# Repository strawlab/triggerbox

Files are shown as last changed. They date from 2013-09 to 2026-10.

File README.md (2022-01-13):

# triggerbox - camera triggering for synchronized multi-camera setups

## Principle of operation

Cameras trigger inputs are connected to pin D9 on an Arduino. (Optionally, a
buffer amplifier can be used. See below for why this may be a good idea.) This
is used to generate a digital pulse which triggers image acquisition on cameras.
Furthermore, a host PC communicates with the Arduino to build a live model of
the clocks on both systems and allows very precise (sub-millisecond)
determination of the timing of trigger pulses from the Arduino. This allows
precise timing information to be taken from the resulting acquired image frames.

## Required hardware:

The minimal required hardware is this:

 - Arduino Nano A000005 (later models WILL NOT WORK).

If using the minimal hardware, you will need to connect pin D9 to the trigger
inputs of your camera directly.

## Optional buffer amplified and circuit board:

For additional robustness for multi-camera setups, particularly those that have
an opto-coupled trigger input which accordingly draws substantially more
current, you will want a buffer amplifier to trigger more cameras. In the
`hardware_v1` and `hardware_v2` directories are the PCB layouts, schematics, and enclosure of the triggerbox.
- Hardware_v1: BNC outputs for triggering only
- Hardware_v2: 4-pin terminal block ouputs for triggering and powering the cameras via external powersource.

## Firmware Build and Install

This firmware can be compiled and installed with the Arduino IDE or at
the command line.

### Option 1: Compiling and Uploading using the Arduino IDE

The file `triggerbox.ino` can be opened directly in the [Arduino
IDE](http://arduino.cc/en/main/software). Set your board to Arduino Nano
("Tools"->"Board"->"Arduino Nano"). Set your port ("Tools"->"Port") correctly,
which depends on your specific computer setup. Then click the "Upload" button.

### Option 2: Command-line Compiling and Uploading using Arduino CLI

To build this firmware for an Arduino Nano on Ubuntu linux, do the following
steps.

Install the required software:

Intall [Arduino CLI](https://arduino.github.io/arduino-cli/latest/), then:

    arduino-cli core update-index
    arduino-cli core install arduino:avr

Compile the firmware

    arduino-cli compile --fqbn arduino:avr:nano

Upload the firmware

    # Note the port `/dev/ttyUSB0` may be different on your computer. In Windows,
    # it will be something like `COM4`.
    arduino-cli upload --port /dev/ttyUSB0 --fqbn arduino:avr:nano

## Testing with host PC

Run the standalone demo program on your host PC. 

 * Prerequisite 1: install [rust](https://rustup.rs/).
 * Prerequisite 2 (linux only): make sure you are in the `dialout` group (or
   whichever group owns the device file - `/dev/ttyUSB0` in the example below):
   ```sudo adduser `whoami` dialout```. 

The demo can be run like this:

    cd braid-triggerbox-rs
    # You may need to change the device path from `/dev/ttyUSB0` in this example.
    # On Windows, this will be something like `COM4` instead of `/dev/ttyUSB0`.
    cargo run -- --device /dev/ttyUSB0 --fps 100
    
If successful, the output will look like:

```
Requested 100 fps, using 100 fps
Connecting to trigger device ..
got new time model: None
.. connected.
got new time model: Some(ClockModel { gain: 0.009991053259000182, offset: 1642089273.653188, residuals: 0.00008373855939680652, n_measurements: 5 })
got new time model: Some(ClockModel { gain: 0.009990740683861077, offset: 1642089273.65347, residuals: 0.00008408054048913982, n_measurements: 6 })
got new time model: Some(ClockModel { gain: 0.009990941849537194, offset: 1642089273.6532729, residuals: 0.00008470585419217969, n_measurements: 7 })
got new time model: Some(ClockModel { gain: 0.0099910874851048, offset: 1642089273.6531227, residuals: 0.00008554253827242064, n_measurements: 8 })
got new time model: Some(ClockModel { gain: 0.009991202969104052, offset: 1642089273.652988, residuals: 0.0000863512614728279, n_measurements: 9 })
got new time model: Some(ClockModel { gain: 0.009991223458200693, offset: 1642089273.652963, residuals: 0.00008639545796995662, n_measurements: 10 })
got new time model: Some(ClockModel { gain: 0.009991292201448232, offset: 1642089273.6528616, residuals: 0.00008692377247143668, n_measurements: 11 })
got new time model: Some(ClockModel { gain: 0.009991496510338038, offset: 1642089273.6525416, residuals: 0.00009343214287582668, n_measurements: 12 })
```

## License

Apache 2.0 or MIT at your choice. See `LICENSE-APACHE` and `LICENSE-MIT`.

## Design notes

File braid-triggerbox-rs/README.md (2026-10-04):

# braid-triggerbox

Host-side driver for the camera synchronization triggerbox used by
[Braid](https://strawlab.org/braid/).

The triggerbox generates the hardware trigger pulses for a multi-camera setup.
This crate talks to it over a USB serial port: it sets the trigger rate, starts
and stops the pulses, and continuously measures the triggerbox clock to build a
model relating trigger pulse numbers to host time. See
[synchronization.md](https://github.com/strawlab/triggerbox/blob/main/synchronization.md)
for the theory of operation.

Two kinds of triggerbox are supported, both speaking the same protocol:

- an Arduino Nano running
  [`triggerbox.ino`](https://github.com/strawlab/triggerbox/blob/main/triggerbox.ino),
  and
- a Raspberry Pi Pico running the
  [Pico firmware](https://github.com/strawlab/triggerbox/tree/main/hardware_v3/braid-triggerbox-firmware-pico).

## Example

`examples/standalone-triggerbox-demo.rs` drives a triggerbox and prints the
clock model as it is updated:

```sh
cargo run --example standalone-triggerbox-demo -- --device /dev/ttyACM0 --fps 100
```

Run it with `--help` for all options. A Pico is ready immediately, so
`--sleep 0.5` shortens the default 7 second wait for an Arduino Nano to reset.

## License

Licensed under either of the Apache License, Version 2.0 or the MIT license, at
your option.

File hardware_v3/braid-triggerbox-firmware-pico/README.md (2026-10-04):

# Braid Triggerbox Firmware for Raspberry Pi Pico

Connections:

GP0 - camera trigger
USB - computer running Braid

## Instructions

Based on [Project template for rp2040-hal](https://github.com/rp-rs/rp2040-project-template).

It includes all of the `knurling-rs` tooling as showcased in https://github.com/knurling-rs/app-template (`defmt`, `defmt-rtt`, `panic-probe`, `flip-link`) to make development as easy as possible.

[`picotool`](https://github.com/raspberrypi/picotool) is configured as the
default runner. Boot the Pico into bootloader mode (hold BOOTSEL while plugging
it in) and then run
```sh
cargo run --release
```

This builds the firmware, loads it over USB, verifies it and reboots the Pico
into it. If you have a debug probe, check out [alternative
runners](#alternative-runners).

The Pico W works too. Note that its onboard LED is driven by the wireless chip,
not GPIO25, so the LED blink in this firmware is not visible on a Pico W.

<!-- TABLE OF CONTENTS -->
<details open="open">

  <summary><h2 style="display: inline-block">Table of Contents</h2></summary>
  <ol>
    <li><a href="#markdown-header-requirements">Requirements</a></li>
    <li><a href="#installation-of-development-dependencies">Installation of development dependencies</a></li>
    <li><a href="#running">Running</a></li>
    <li><a href="#alternative-runners">Alternative runners</a></li>
    <li><a href="#roadmap">Roadmap</a></li>
    <li><a href="#contributing">Contributing</a></li>
    <li><a href="#code-of-conduct">Code of conduct</a></li>
    <li><a href="#license">License</a></li>
    <li><a href="#contact">Contact</a></li>
  </ol>
</details>

<!-- Requirements -->
<details open="open">
  <summary><h2 style="display: inline-block" id="requirements">Requirements</h2></summary>

- The standard Rust tooling (cargo, rustup) which you can install from https://rustup.rs/

- Toolchain support for the cortex-m0+ processors in the rp2040 (thumbv6m-none-eabi)

- flip-link - this allows you to detect stack-overflows on the first core, which is the only supported target for now.

- picotool (the default runner), version 2.0 or later.

- Optionally, for debugging: probe-rs and a CMSIS-DAP probe. You can use a second Raspberry Pi Pico as a CMSIS-DAP probe debugger.

  - Download this file: https://github.com/majbthrd/DapperMime/releases/download/20210225/raspberry_pi_pico-DapperMime.uf2
  - Boot the Pico in bootloader mode by holding the bootset button while plugging it in
  - Open the drive RPI-RP2 when prompted
  - Copy raspberry_pi_pico-DapperMime.uf2 from Downloads into RPI-RP2
  - Connect the debug pins of your CMSIS-DAP Pico to the target one
      - Connect GP2 on the Probe to SWCLK on the Target
      - Connect GP3 on the Probe to SWDIO on the Target
      - Connect a ground line from the CMSIS-DAP Probe to the Target too

</details>

<!-- Installation of development dependencies -->
<details open="open">
  <summary><h2 style="display: inline-block" id="installation-of-development-dependencies">Installation of development dependencies</h2></summary>

```sh
rustup target install thumbv6m-none-eabi
cargo install flip-link
# The default 'runner'. On macOS:
brew install picotool
# On Linux, see below. On other platforms, see https://github.com/raspberrypi/picotool
```

#### picotool on Debian and Ubuntu

On Debian 13 (trixie) or later, install the packaged version, which also
installs udev rules so picotool works without `sudo`:

```sh
sudo apt install picotool
```

Ubuntu only packages picotool from 26.10 onwards, and Debian 12 (bookworm)
does not package it, so build it from source there. picotool needs the Pico
SDK source to build:

```sh
sudo apt install build-essential pkg-config libusb-1.0-0-dev cmake git
git clone --depth 1 --branch 2.3.1 https://github.com/raspberrypi/pico-sdk.git
git clone --depth 1 --branch 2.3.1 https://github.com/raspberrypi/picotool.git
cmake -S picotool -B picotool/build -DPICO_SDK_PATH=$PWD/pico-sdk
cmake --build picotool/build -j
sudo cmake --install picotool/build
# Allow access to the Pico in bootloader mode without sudo:
sudo cp picotool/udev/60-picotool.rules /etc/udev/rules.d/
sudo udevadm control --reload-rules && sudo udevadm trigger
```

Alternatively, prebuilt Linux binaries are available from
[pico-sdk-tools](https://github.com/raspberrypi/pico-sdk-tools/releases) (you
still need `libusb-1.0-0` and the udev rules above).

Check the installation with `picotool version` (it must report 2.0 or later
and must not say it was compiled without USB support). With the Pico in
bootloader mode, `picotool info` should list it.

</details>

<!-- Running -->
<details open="open">
  <summary><h2 style="display: inline-block" id="running">Running</h2></summary>

For a debug build
```sh
cargo run
```
For a release build
```sh
cargo run --release
```

`defmt` log output is only shown when using the debug probe runner (see
[alternative runners](#alternative-runners)).

If you do not specify a DEFMT_LOG level, it will be set to `debug`.
That means `println!("")`, `info!("")` and `debug!("")` statements will be printed.
If you wish to override this, you can change it in `.cargo/config.toml`
```toml
[env]
DEFMT_LOG = "off"
```
You can also set this inline (on Linux/MacOS)
```sh
DEFMT_LOG=trace cargo run
```

or set the _environment variable_ so that it applies to every `cargo run` call that follows:
#### Linux/MacOS/unix
```sh
export DEFMT_LOG=trace
```

Setting the DEFMT_LOG level for the current session
for bash
```sh
export DEFMT_LOG=trace
```

#### Windows
Windows users can only override DEFMT_LOG through `config.toml`
or by setting the environment variable as a separate step before calling `cargo run`
- cmd
```cmd
set DEFMT_LOG=trace
```
- powershell
```ps1
$Env:DEFMT_LOG = trace
```

```cmd
cargo run
```

</details>
<!-- ALTERNATIVE RUNNERS -->
<details open="open">
  <summary><h2 style="display: inline-block" id="alternative-runners">Alternative runners</h2></summary>

The runner is set in `.cargo/config.toml`. Some alternatives are listed below.

* **Loading with picotool (default)**

  ```toml
  runner = "picotool load -u -v -x -t elf"
  ```

  picotool talks to the RP2040 bootloader over its PICOBOOT USB interface. The
  Pico must be in bootloader mode (hold BOOTSEL while plugging it in).

* **Loading a UF2 over USB mass storage**

  ```console
  $ cargo install elf2uf2-rs --locked
  ```

  ```toml
  runner = "elf2uf2-rs -d"
  ```

  This builds a UF2 file and copies it to the `RPI-RP2` drive that appears in
  bootloader mode. On Linux, you need to mount the drive first. On recent macOS
  versions, writing to this drive can hang indefinitely, which is why picotool
  is the default.

* **Using a debug probe**

  ```console
  $ cargo install probe-rs-tools --locked
  ```

  ```toml
  runner = "probe-rs run --chip RP2040"
  ```

  This needs a CMSIS-DAP probe (see [requirements](#requirements)) but does not
  need the Pico to be in bootloader mode, and it shows `defmt` log output.

</details>

## License

The contents of this repository are dual-licensed under the _MIT OR Apache
2.0_ License. That means you can chose either the MIT licence or the
Apache-2.0 licence when you re-use this code. See `MIT` or `APACHE2.0` for more
information on each specific licence.

Any submissions to this project (e.g. as Pull Requests) must be made available
under these terms.

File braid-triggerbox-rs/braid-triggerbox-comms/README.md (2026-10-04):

# braid-triggerbox-comms

The protocol spoken between the host and the
[Braid](https://strawlab.org/braid/) camera synchronization triggerbox
firmware.

This crate is shared by the host library,
[`braid-triggerbox`](https://crates.io/crates/braid-triggerbox), and the
[Raspberry Pi Pico firmware](https://github.com/strawlab/triggerbox/tree/main/hardware_v3/braid-triggerbox-firmware-pico).
It is `no_std` when the default `std` feature is disabled. Enable the `defmt`
feature for [`defmt`](https://defmt.ferrous-systems.com/) formatting on the
device.

## License

Licensed under either of the Apache License, Version 2.0 or the MIT license, at
your option.

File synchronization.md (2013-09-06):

synchronization
===============

The most significant technical challenge is synchronizing the clock of
your computer with the luminance samples made by the USB device.

Sub-millisecond synchronization between your computer and USB device
--------------------------------------------------------------------

To allow your computer to determine exactly when samples were
acquired, a simple protocol involving timestamp exchange is
implemented between the host computer and the USB device. The host
sends a request to the arduino, keeping note of the time the request
was made (`T_host_request`). The lagtestino firmware responds to this
request by sending the current value of its clock (`C_arduino`). The
host records the time of arrival of this new data
(`T_host_receive`). By assuming that delays are symmetric and only
accepting responses that occur within a short latency (thus bounding
maximal error), the host calculates that the device's timetamp
occurred at `T_arduino_estimate`:

    request_response_roundtrip_duration = T_host_receive - T_host_request
    if request_response_roundtrip_duration < maximal_acceptable_error:
        T_arduino_estimate = (T_host_request + T_host_receive) / 2

So `T_arduino_estimate` is the best guess as to when `C_arduino` was
sampled, in the host computer's timebase. After many such samples, we
have two corresponding vectors:

    T = [ T_arduino_estimate[0], T_arduino_estimate[1], ... ]
    C = [ C_arduino[0],          C_arduino[1],          ... ]

We can now model the relation between the two clocks with:

    T = gain*C + offset

The values of `gain` and `offset` can be found by a least-squares fit
from the acquired vectors `T` and `C`. Doing so allows conversion from
any arduino clock value (`C_arduino`) to be directly converted to a
timestamp of the host computer.

This is concept is a simplification of the ideas contained in the IEEE
1588 specification but is sufficient for acheiving sub-millisecond
timing precision between an arduino and unpriviledged software.

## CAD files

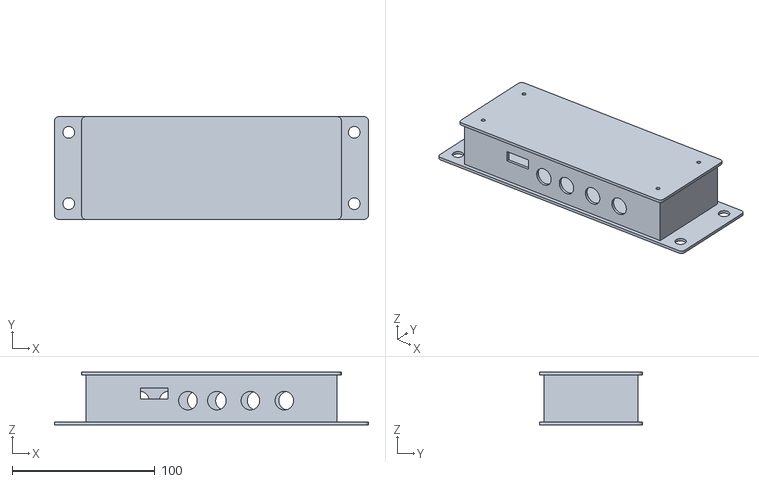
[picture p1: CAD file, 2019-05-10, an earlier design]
hardware_v1/enclosure/rendered/enclosure_assembly.stl
220.0 x 72.0 x 37.0

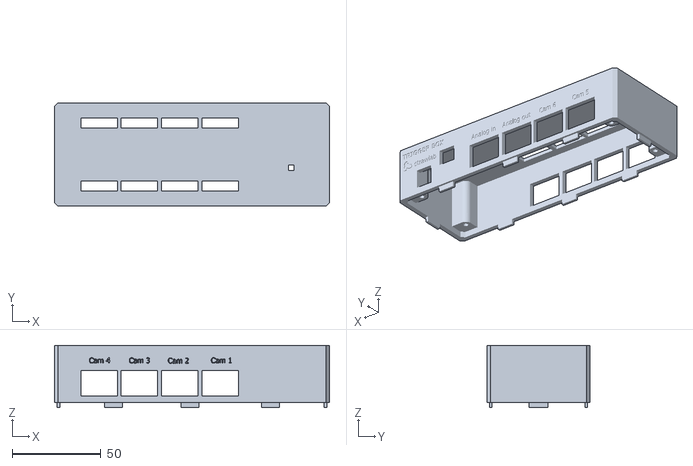
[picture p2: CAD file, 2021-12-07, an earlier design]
hardware_v2/enclosure/cover.stl
154.5 x 58.0 x 35.0

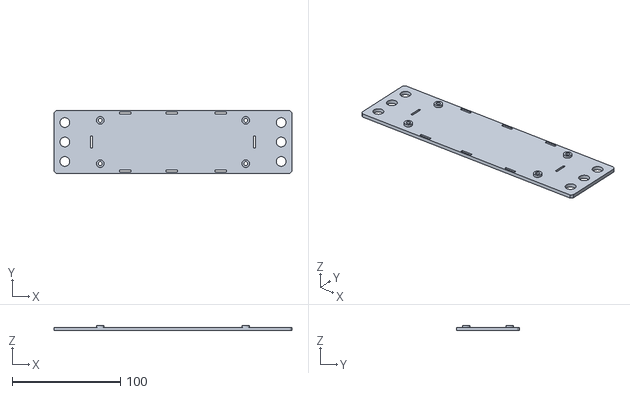
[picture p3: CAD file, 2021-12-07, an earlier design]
hardware_v2/enclosure/base_200.stl
220.0 x 58.0 x 5.00

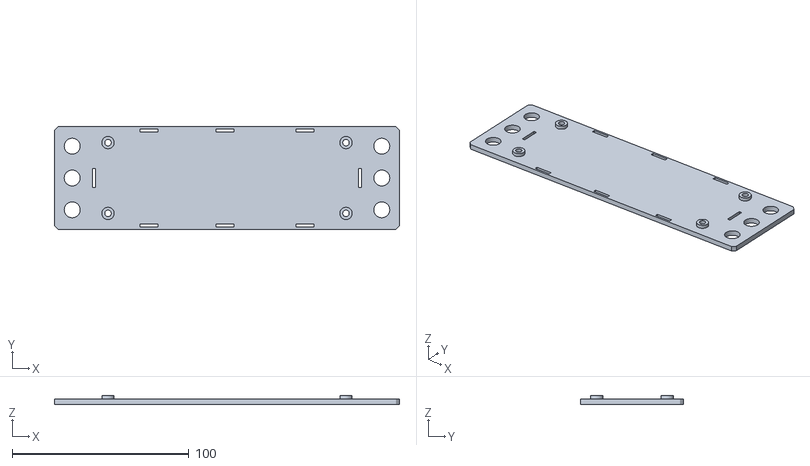
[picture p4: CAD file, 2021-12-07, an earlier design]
hardware_v2/enclosure/base_175.stl
195.0 x 58.0 x 5.00

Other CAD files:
hardware_v1/enclosure/rendered/enclosure_assembly.scad
hardware_v2/enclosure/body.ipt

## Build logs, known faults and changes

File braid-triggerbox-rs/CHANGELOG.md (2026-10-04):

# Changelog

All notable changes to this project are documented in this file.

The format is based on [Keep a Changelog](https://keepachangelog.com/en/1.1.0/),
and this project adheres to [Semantic Versioning](https://semver.org/spec/v2.0.0.html).

## [0.5.0](https://github.com/strawlab/triggerbox/compare/braid-triggerbox/0.4.2...braid-triggerbox/0.5.0) - 2026-10-04

### Added
- *(braid-triggerbox)* [**breaking**] take TriggerboxOptions in TriggerboxDevice::new

### Changed
- *(braid-triggerbox-comms)* [**breaking**] replace bbqueue with a plain buffer

### Dependencies
- *(deps)* update braid-triggerbox dependencies
- *(deps)* [**breaking**] update braid-triggerbox-comms to fugit 0.6 and defmt 1

### Documentation
- update stale READMEs, comments and demo defaults

### Fixed
- [**breaking**] never panic in the firmware on data from the host
- *(braid-triggerbox)* handle device data without panicking
- *(braid-triggerbox-comms)* parse N= (set device name)
- *(braid-triggerbox)* always send two CRC digits when setting the name
- *(braid-triggerbox)* resynchronize on corrupted data from the device

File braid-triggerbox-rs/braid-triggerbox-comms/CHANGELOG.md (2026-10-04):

# Changelog

All notable changes to this project are documented in this file.

The format is based on [Keep a Changelog](https://keepachangelog.com/en/1.1.0/),
and this project adheres to [Semantic Versioning](https://semver.org/spec/v2.0.0.html).

## [0.2.0](https://github.com/strawlab/triggerbox/compare/braid-triggerbox-comms/0.1.0...braid-triggerbox-comms/0.2.0) - 2026-10-04

### Changed
- *(braid-triggerbox-comms)* [**breaking**] replace bbqueue with a plain buffer

### Dependencies
- *(deps)* [**breaking**] update braid-triggerbox-comms to fugit 0.6 and defmt 1

### Fixed
- [**breaking**] never panic in the firmware on data from the host
- *(braid-triggerbox-comms)* parse N= (set device name)

### Other
- clippy fix
- clippy fixes
- remove non-backwards compatible firmware
- update rp-pico 0.2.0 -> 0.6.0
- add test encode/decode tests for all message types
- bugfix: many interrupted messages
- sleep duration is part of API
- cargo clippy fix
- move clock emulation code
- flexible clock freq
- better naming
- cleanup
- cleanup
- cleanup
- add docstrings

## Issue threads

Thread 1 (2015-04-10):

can't fit time model at 15/30 hz

nzjrs, 2015-04-10:
Actually this is probbably not due to the actual value, but due to some state not being properly cleared, as the first time setting it to those frequencies works, but not the second.

see unstable branch for test case. @astraw can you reproduce this too?

astraw, 2021-08-13:
Actually it works for me now.

Closed 2021-08-13.

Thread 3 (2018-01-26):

Arduino make and upload fails

llorban, 2018-01-26:
I built a trigger box and trying to make and upload the firmware on it. When running
`make -f ../Makefile.uno upload`
the following error is generated:
`/usr/share/arduino/Arduino.mk:772: *** At least one source file (*.ino, *.pde, *.cpp, *c, *cc, *.S) is needed.  Stop.`

Here is the full output:
```
make -f '/home/flightlab/Documents/triggerbox-master/firmware/triggerbox/Makefile.uno' upload
-------------------------
Arduino.mk Configuration:
- [AUTODETECTED]       CURRENT_OS = LINUX
- [USER]               ARDUINO_DIR = /usr/share/arduino
- [COMPUTED]           ARDMK_DIR = /usr/share/arduino (relative to Common.mk)
- [AUTODETECTED]       ARDUINO_VERSION = 105
- [DEFAULT]            ARCHITECTURE =
- [DEFAULT]            VENDOR = arduino
- [DEFAULT]            ARDUINO_SKETCHBOOK =
- [BUNDLED]            AVR_TOOLS_DIR = /usr/share/arduino/hardware/tools/avr (in Arduino distribution)
- [COMPUTED]           ARDUINO_LIB_PATH = /usr/share/arduino/libraries (from ARDUINO_DIR)
- [COMPUTED]           ARDUINO_VAR_PATH = /usr/share/arduino/hardware/arduino//variants (from ARDUINO_DIR)
- [COMPUTED]           BOARDS_TXT = /usr/share/arduino/hardware/arduino//boards.txt (from ARDUINO_DIR)
- [DEFAULT]            USER_LIB_PATH = /libraries (in user sketchbook)
- [DEFAULT]            PRE_BUILD_HOOK = pre-build-hook.sh
- [USER]               BOARD_TAG = uno
- [COMPUTED]           CORE = arduino (from build.core)
- [COMPUTED]           VARIANT = standard (from build.variant)
- [COMPUTED]           OBJDIR = build-uno (from BOARD_TAG)
- [COMPUTED]           ARDUINO_CORE_PATH = /usr/share/arduino/hardware/arduino//cores/arduino (from ARDUINO_DIR, BOARD_TAG and boards.txt)
/usr/share/arduino/Arduino.mk:772: *** At least one source file (*.ino, *.pde, *.cpp, *c, *cc, *.S) is needed.  Stop.

```

llorban, 2018-01-26:
This was resolved -- had to cd into the location of the file

Closed 2018-01-26.

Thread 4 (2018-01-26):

firmware upload fails

llorban, 2018-01-26:
Here is the error

```
mkdir -p build-uno
make reset
make[1]: Entering directory '/home/flightlab/Documents/triggerbox-master/firmware/triggerbox'
make[1]: *** No rule to make target 'reset'.  Stop.
make[1]: Leaving directory '/home/flightlab/Documents/triggerbox-master/firmware/triggerbox'
/usr/share/arduino/Arduino.mk:1408: recipe for target 'upload' failed
make: *** [upload] Error 2
```

The Arduino IDE is running and I am able to get "board info" so connection to the Arduino is confirmed. The Arduino is on port /dev/ttyACM0 and the make file appears to look there (/dev/ttyACM*)

astraw, 2018-01-26:
Why are you trying to do `make reset`? As specified in `README.md`, try one of these:

    make -f Makefile.nano upload # <- Do this for Arduino Nano
    make -f Makefile.uno upload # <- Do this for Arduino Uno

llorban, 2018-01-26:
I didn't do a `make reset` -- followed the readme.md word for word

llorban, 2018-01-26:
Here is the full output including my command

```
make -f Makefile.uno upload
-------------------------
Arduino.mk Configuration:
- [AUTODETECTED]       CURRENT_OS = LINUX
- [USER]               ARDUINO_DIR = /usr/share/arduino
- [COMPUTED]           ARDMK_DIR = /usr/share/arduino (relative to Common.mk)
- [AUTODETECTED]       ARDUINO_VERSION = 105
- [DEFAULT]            ARCHITECTURE =
- [DEFAULT]            VENDOR = arduino
- [DEFAULT]            ARDUINO_SKETCHBOOK =
- [BUNDLED]            AVR_TOOLS_DIR = /usr/share/arduino/hardware/tools/avr (in Arduino distribution)
- [COMPUTED]           ARDUINO_LIB_PATH = /usr/share/arduino/libraries (from ARDUINO_DIR)
- [COMPUTED]           ARDUINO_VAR_PATH = /usr/share/arduino/hardware/arduino//variants (from ARDUINO_DIR)
- [COMPUTED]           BOARDS_TXT = /usr/share/arduino/hardware/arduino//boards.txt (from ARDUINO_DIR)
- [DEFAULT]            USER_LIB_PATH = /libraries (in user sketchbook)
- [DEFAULT]            PRE_BUILD_HOOK = pre-build-hook.sh
- [USER]               BOARD_TAG = uno
- [COMPUTED]           CORE = arduino (from build.core)
- [COMPUTED]           VARIANT = standard (from build.variant)
- [COMPUTED]           OBJDIR = build-uno (from BOARD_TAG)
- [COMPUTED]           ARDUINO_CORE_PATH = /usr/share/arduino/hardware/arduino//cores/arduino (from ARDUINO_DIR, BOARD_TAG and boards.txt)
- [DETECTED]           MONITOR_BAUDRATE = 115200  (in sketch)
- [DEFAULT]            OPTIMIZATION_LEVEL = s
- [DEFAULT]            MCU_FLAG_NAME = mmcu
- [DEFAULT]            CFLAGS_STD =
- [DEFAULT]            CXXFLAGS_STD =
- [COMPUTED]           DEVICE_PATH = /dev/trig* /dev/ttyACM* (from MONITOR_PORT)
- [DEFAULT]            FORCE_MONITOR_PORT =
- [AUTODETECTED]       Size utility: AVR-aware for enhanced output
-
-                      ARDUINO_LIBS =
- [SYSTEM]               EEPROM
- [SYSTEM]               SPI
- [SYSTEM]               UDEV
- [COMPUTED]           BOOTLOADER_PARENT = /usr/share/arduino/hardware/arduino//bootloaders (from ARDUINO_DIR)
- [COMPUTED]           ARDMK_VERSION = 1.5
- [COMPUTED]           CC_VERSION = 4.9.2 (avr-gcc)
-------------------------
mkdir -p build-uno
make reset
make[1]: Entering directory '/home/flightlab/Documents/triggerbox-master/firmware/triggerbox'
make[1]: *** No rule to make target 'reset'.  Stop.
make[1]: Leaving directory '/home/flightlab/Documents/triggerbox-master/firmware/triggerbox'
/usr/share/arduino/Arduino.mk:1408: recipe for target 'upload' failed
make: *** [upload] Error 2
```

astraw, 2018-01-26:
Are you running `make -f Makefile.uno upload` in the directory `firmware/triggerbox`? I guess so.

This is very strange. The file `Makefile.uno` is just sets a few configuration variables and then defers to the file `/usr/share/arduino/Arduino.mk`, which is obviously found. This `Arduino.mk` then calls another make target (`make reset`) which is in the `Arduino.mk` file again.

Perhaps try renaming `Makefile.uno` to `Makefile` and then, instead of `make -f Makefile.uno upload`, just run `make upload`.

llorban, 2018-01-27:
Thank you, your suggestion helped get past this error, but it failed with another one:
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
astraw, 2018-01-27:
If you look at the error, you will see `Permission denied: '/dev/ttyACM0'`. There are a few ways to deal with this. Probably easiest is to run the command with superuser privileges: `sudo make upload`.

llorban, 2018-01-27:
I think this worked-- here is the output:

```
-------------------------
Arduino.mk Configuration:
- [AUTODETECTED]       CURRENT_OS = LINUX
- [USER]               ARDUINO_DIR = /usr/share/arduino
- [COMPUTED]           ARDMK_DIR = /usr/share/arduino (relative to Common.mk)
- [AUTODETECTED]       ARDUINO_VERSION = 105
- [DEFAULT]            ARCHITECTURE =
- [DEFAULT]            VENDOR = arduino
- [DEFAULT]            ARDUINO_SKETCHBOOK =
- [BUNDLED]            AVR_TOOLS_DIR = /usr/share/arduino/hardware/tools/avr (in Arduino distribution)
- [COMPUTED]           ARDUINO_LIB_PATH = /usr/share/arduino/libraries (from ARDUINO_DIR)
- [COMPUTED]           ARDUINO_VAR_PATH = /usr/share/arduino/hardware/arduino//variants (from ARDUINO_DIR)
- [COMPUTED]           BOARDS_TXT = /usr/share/arduino/hardware/arduino//boards.txt (from ARDUINO_DIR)
- [DEFAULT]            USER_LIB_PATH = /libraries (in user sketchbook)
- [DEFAULT]            PRE_BUILD_HOOK = pre-build-hook.sh
- [USER]               BOARD_TAG = uno
- [COMPUTED]           CORE = arduino (from build.core)
- [COMPUTED]           VARIANT = standard (from build.variant)
- [COMPUTED]           OBJDIR = build-uno (from BOARD_TAG)
- [COMPUTED]           ARDUINO_CORE_PATH = /usr/share/arduino/hardware/arduino//cores/arduino (from ARDUINO_DIR, BOARD_TAG and boards.txt)
- [DETECTED]           MONITOR_BAUDRATE = 115200  (in sketch)
- [DEFAULT]            OPTIMIZATION_LEVEL = s
- [DEFAULT]            MCU_FLAG_NAME = mmcu
- [DEFAULT]            CFLAGS_STD =
- [DEFAULT]            CXXFLAGS_STD =
- [COMPUTED]           DEVICE_PATH = /dev/trig* /dev/ttyACM* (from MONITOR_PORT)
- [DEFAULT]            FORCE_MONITOR_PORT =
- [AUTODETECTED]       Size utility: AVR-aware for enhanced output
-
-                      ARDUINO_LIBS =
- [SYSTEM]               EEPROM
- [SYSTEM]               SPI
- [SYSTEM]               UDEV
- [COMPUTED]           BOOTLOADER_PARENT = /usr/share/arduino/hardware/arduino//bootloaders (from ARDUINO_DIR)
- [COMPUTED]           ARDMK_VERSION = 1.5
- [COMPUTED]           CC_VERSION = 4.9.2 (avr-gcc)
-------------------------
mkdir -p build-uno
/usr/share/arduino/hardware/tools/avr/bin/avr-g++ -x c++ -include Arduino.h -MMD -c -mmcu=atmega328p -DF_CPU=16000000L -DARDUINO=105  -D__PROG_TYPES_COMPAT__ -I/usr/share/arduino/hardware/arduino//cores/arduino -I/usr/share/arduino/hardware/arduino//variants/standard    -I/usr/share/arduino/libraries/EEPROM    -I/usr/share/arduino/libraries/SPI    -I/usr/share/arduino/libraries/UDEV   -Wall -ffunction-sections -fdata-sections -Os -fno-exceptions  triggerbox.ino -o build-uno/triggerbox.o
/usr/share/arduino/hardware/tools/avr/bin/avr-gcc -mmcu=atmega328p -Wl,--gc-sections -Os -o build-uno/triggerbox.elf build-uno/triggerbox.o build-uno/libcore.a  -lc -lm
/usr/share/arduino/hardware/tools/avr/bin/avr-objcopy -O ihex -R .eeprom build-uno/triggerbox.elf build-uno/triggerbox.hex

/usr/share/arduino/hardware/tools/avr/bin/avr-size --mcu=atmega328p -C --format=avr build-uno/triggerbox.elf
AVR Memory Usage
----------------
Device: atmega328p

Program:    6372 bytes (19.4% Full)
(.text + .data + .bootloader)

Data:        243 bytes (11.9% Full)
(.data + .bss + .noinit)

make reset
make[1]: Entering directory '/home/llorban/Documents/triggerbox-master/firmware/triggerbox'
/usr/bin/ard-reset-arduino  /dev/ttyACM0
make[1]: Leaving directory '/home/llorban/Documents/triggerbox-master/firmware/triggerbox'
make do_upload
make[1]: Entering directory '/home/llorban/Documents/triggerbox-master/firmware/triggerbox'
/usr/share/arduino/hardware/tools/avr/../avrdude -q -V -p atmega328p -C /usr/share/arduino/hardware/tools/avr/../avrdude.conf -D -c arduino -b 115200 -P /dev/ttyACM0 \
		-U flash:w:build-uno/triggerbox.hex:i

avrdude: AVR device initialized and ready to accept instructions
avrdude: Device signature = 0x1e950f (probably m328p)
avrdude: reading input file "build-uno/triggerbox.hex"
avrdude: writing flash (6372 bytes):
avrdude: 6372 bytes of flash written

avrdude: safemode: Fuses OK (E:00, H:00, L:00)

avrdude done.  Thank you.

make[1]: Leaving directory '/home/llorban/Documents/triggerbox-master/firmware/triggerbox'

```

Closed 2018-01-28.

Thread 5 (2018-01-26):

Compilation error

llorban, 2018-01-26:
I tried compiling using Arduino IDE and received the following error message:

```
Arduino: 1.8.5 (Linux), Board: "Arduino/Genuino Uno"

/home/flightlab/arduino-1.8.5/arduino-builder -dump-prefs -logger=machine -hardware /home/flightlab/arduino-1.8.5/hardware -tools /home/flightlab/arduino-1.8.5/tools-builder -tools /home/flightlab/arduino-1.8.5/hardware/tools/avr -built-in-libraries /home/flightlab/arduino-1.8.5/libraries -libraries /home/flightlab/Arduino/libraries -fqbn=arduino:avr:uno -vid-pid=0X2A03_0X0043 -ide-version=10805 -build-path /tmp/arduino_build_21516 -warnings=none -build-cache /tmp/arduino_cache_24644 -prefs=build.warn_data_percentage=75 -prefs=runtime.tools.arduinoOTA.path=/home/flightlab/arduino-1.8.5/hardware/tools/avr -prefs=runtime.tools.avr-gcc.path=/home/flightlab/arduino-1.8.5/hardware/tools/avr -prefs=runtime.tools.avrdude.path=/home/flightlab/arduino-1.8.5/hardware/tools/avr -verbose /home/flightlab/Documents/triggerbox-master/firmware/triggerbox/triggerbox.ino
/home/flightlab/arduino-1.8.5/arduino-builder -compile -logger=machine -hardware /home/flightlab/arduino-1.8.5/hardware -tools /home/flightlab/arduino-1.8.5/tools-builder -tools /home/flightlab/arduino-1.8.5/hardware/tools/avr -built-in-libraries /home/flightlab/arduino-1.8.5/libraries -libraries /home/flightlab/Arduino/libraries -fqbn=arduino:avr:uno -vid-pid=0X2A03_0X0043 -ide-version=10805 -build-path /tmp/arduino_build_21516 -warnings=none -build-cache /tmp/arduino_cache_24644 -prefs=build.warn_data_percentage=75 -prefs=runtime.tools.arduinoOTA.path=/home/flightlab/arduino-1.8.5/hardware/tools/avr -prefs=runtime.tools.avr-gcc.path=/home/flightlab/arduino-1.8.5/hardware/tools/avr -prefs=runtime.tools.avrdude.path=/home/flightlab/arduino-1.8.5/hardware/tools/avr -verbose /home/flightlab/Documents/triggerbox-master/firmware/triggerbox/triggerbox.ino
Using board 'uno' from platform in folder: /home/flightlab/arduino-1.8.5/hardware/arduino/avr
Using core 'arduino' from platform in folder: /home/flightlab/arduino-1.8.5/hardware/arduino/avr
Detecting libraries used...
"/home/flightlab/arduino-1.8.5/hardware/tools/avr/bin/avr-g++" -c -g -Os -w -std=gnu++11 -fpermissive -fno-exceptions -ffunction-sections -fdata-sections -fno-threadsafe-statics  -flto -w -x c++ -E -CC -mmcu=atmega328p -DF_CPU=16000000L -DARDUINO=10805 -DARDUINO_AVR_UNO -DARDUINO_ARCH_AVR   "-I/home/flightlab/arduino-1.8.5/hardware/arduino/avr/cores/arduino" "-I/home/flightlab/arduino-1.8.5/hardware/arduino/avr/variants/standard" "/tmp/arduino_build_21516/sketch/triggerbox.ino.cpp" -o "/dev/null"
"/home/flightlab/arduino-1.8.5/hardware/tools/avr/bin/avr-g++" -c -g -Os -w -std=gnu++11 -fpermissive -fno-exceptions -ffunction-sections -fdata-sections -fno-threadsafe-statics  -flto -w -x c++ -E -CC -mmcu=atmega328p -DF_CPU=16000000L -DARDUINO=10805 -DARDUINO_AVR_UNO -DARDUINO_ARCH_AVR   "-I/home/flightlab/arduino-1.8.5/hardware/arduino/avr/cores/arduino" "-I/home/flightlab/arduino-1.8.5/hardware/arduino/avr/variants/standard" "-I/home/flightlab/arduino-1.8.5/hardware/arduino/avr/libraries/EEPROM/src" "/tmp/arduino_build_21516/sketch/triggerbox.ino.cpp" -o "/dev/null"
"/home/flightlab/arduino-1.8.5/hardware/tools/avr/bin/avr-g++" -c -g -Os -w -std=gnu++11 -fpermissive -fno-exceptions -ffunction-sections -fdata-sections -fno-threadsafe-statics  -flto -w -x c++ -E -CC -mmcu=atmega328p -DF_CPU=16000000L -DARDUINO=10805 -DARDUINO_AVR_UNO -DARDUINO_ARCH_AVR   "-I/home/flightlab/arduino-1.8.5/hardware/arduino/avr/cores/arduino" "-I/home/flightlab/arduino-1.8.5/hardware/arduino/avr/variants/standard" "-I/home/flightlab/arduino-1.8.5/hardware/arduino/avr/libraries/EEPROM/src" "-I/home/flightlab/arduino-1.8.5/hardware/arduino/avr/libraries/SPI/src" "/tmp/arduino_build_21516/sketch/triggerbox.ino.cpp" -o "/dev/null"
"/home/flightlab/arduino-1.8.5/hardware/tools/avr/bin/avr-g++" -c -g -Os -w -std=gnu++11 -fpermissive -fno-exceptions -ffunction-sections -fdata-sections -fno-threadsafe-statics  -flto -w -x c++ -E -CC -mmcu=atmega328p -DF_CPU=16000000L -DARDUINO=10805 -DARDUINO_AVR_UNO -DARDUINO_ARCH_AVR   "-I/home/flightlab/arduino-1.8.5/hardware/arduino/avr/cores/arduino" "-I/home/flightlab/arduino-1.8.5/hardware/arduino/avr/variants/standard" "-I/home/flightlab/arduino-1.8.5/hardware/arduino/avr/libraries/EEPROM/src" "-I/home/flightlab/arduino-1.8.5/hardware/arduino/avr/libraries/SPI/src" "/tmp/arduino_build_21516/sketch/triggerbox.ino.cpp" -o "/tmp/arduino_build_21516/preproc/ctags_target_for_gcc_minus_e.cpp"
/home/flightlab/Documents/triggerbox-master/firmware/triggerbox/triggerbox.ino:28:18: fatal error: UDEV.h: No such file or directory
 #include <UDEV.h>
                  ^
compilation terminated.
Using library EEPROM at version 2.0 in folder: /home/flightlab/arduino-1.8.5/hardware/arduino/avr/libraries/EEPROM
Using library SPI at version 1.0 in folder: /home/flightlab/arduino-1.8.5/hardware/arduino/avr/libraries/SPI
exit status 1
Error compiling for board Arduino/Genuino Uno.
```

astraw, 2018-01-26:
Hmm, this seems to be a path problem for the IDE to find `UDEV.h`. Please install the `arduino-udev` package from our debian repository. If a line with debs.strawlab.org is already in your `/etc/apt/sources.list` file, you should just need to do `apt-get install arduino-udev`.

If it still doesn't work to compile in the IDE, please also try compiling from the command line as specified in `README.md`.

llorban, 2018-01-27:
I successfully installed arduino-udev, but the script still fails on missing udev.h. I restarted the system just to be sure:

```
Arduino: 1.8.5 (Linux), Board: "Arduino/Genuino Uno"

/home/flightlab/arduino-1.8.5/arduino-builder -dump-prefs -logger=machine -hardware /home/flightlab/arduino-1.8.5/hardware -tools /home/flightlab/arduino-1.8.5/tools-builder -tools /home/flightlab/arduino-1.8.5/hardware/tools/avr -built-in-libraries /home/flightlab/arduino-1.8.5/libraries -libraries /home/flightlab/Arduino/libraries -fqbn=arduino:avr:uno -vid-pid=0X2A03_0X0043 -ide-version=10805 -build-path /tmp/arduino_build_435484 -warnings=none -build-cache /tmp/arduino_cache_68279 -prefs=build.warn_data_percentage=75 -prefs=runtime.tools.arduinoOTA.path=/home/flightlab/arduino-1.8.5/hardware/tools/avr -prefs=runtime.tools.avr-gcc.path=/home/flightlab/arduino-1.8.5/hardware/tools/avr -prefs=runtime.tools.avrdude.path=/home/flightlab/arduino-1.8.5/hardware/tools/avr -verbose /home/flightlab/Documents/triggerbox-master/firmware/triggerbox/triggerbox.ino
/home/flightlab/arduino-1.8.5/arduino-builder -compile -logger=machine -hardware /home/flightlab/arduino-1.8.5/hardware -tools /home/flightlab/arduino-1.8.5/tools-builder -tools /home/flightlab/arduino-1.8.5/hardware/tools/avr -built-in-libraries /home/flightlab/arduino-1.8.5/libraries -libraries /home/flightlab/Arduino/libraries -fqbn=arduino:avr:uno -vid-pid=0X2A03_0X0043 -ide-version=10805 -build-path /tmp/arduino_build_435484 -warnings=none -build-cache /tmp/arduino_cache_68279 -prefs=build.warn_data_percentage=75 -prefs=runtime.tools.arduinoOTA.path=/home/flightlab/arduino-1.8.5/hardware/tools/avr -prefs=runtime.tools.avr-gcc.path=/home/flightlab/arduino-1.8.5/hardware/tools/avr -prefs=runtime.tools.avrdude.path=/home/flightlab/arduino-1.8.5/hardware/tools/avr -verbose /home/flightlab/Documents/triggerbox-master/firmware/triggerbox/triggerbox.ino
Using board 'uno' from platform in folder: /home/flightlab/arduino-1.8.5/hardware/arduino/avr
Using core 'arduino' from platform in folder: /home/flightlab/arduino-1.8.5/hardware/arduino/avr
Detecting libraries used...
"/home/flightlab/arduino-1.8.5/hardware/tools/avr/bin/avr-g++" -c -g -Os -w -std=gnu++11 -fpermissive -fno-exceptions -ffunction-sections -fdata-sections -fno-threadsafe-statics  -flto -w -x c++ -E -CC -mmcu=atmega328p -DF_CPU=16000000L -DARDUINO=10805 -DARDUINO_AVR_UNO -DARDUINO_ARCH_AVR   "-I/home/flightlab/arduino-1.8.5/hardware/arduino/avr/cores/arduino" "-I/home/flightlab/arduino-1.8.5/hardware/arduino/avr/variants/standard" "/tmp/arduino_build_435484/sketch/triggerbox.ino.cpp" -o "/dev/null"
"/home/flightlab/arduino-1.8.5/hardware/tools/avr/bin/avr-g++" -c -g -Os -w -std=gnu++11 -fpermissive -fno-exceptions -ffunction-sections -fdata-sections -fno-threadsafe-statics  -flto -w -x c++ -E -CC -mmcu=atmega328p -DF_CPU=16000000L -DARDUINO=10805 -DARDUINO_AVR_UNO -DARDUINO_ARCH_AVR   "-I/home/flightlab/arduino-1.8.5/hardware/arduino/avr/cores/arduino" "-I/home/flightlab/arduino-1.8.5/hardware/arduino/avr/variants/standard" "-I/home/flightlab/arduino-1.8.5/hardware/arduino/avr/libraries/EEPROM/src" "/tmp/arduino_build_435484/sketch/triggerbox.ino.cpp" -o "/dev/null"
"/home/flightlab/arduino-1.8.5/hardware/tools/avr/bin/avr-g++" -c -g -Os -w -std=gnu++11 -fpermissive -fno-exceptions -ffunction-sections -fdata-sections -fno-threadsafe-statics  -flto -w -x c++ -E -CC -mmcu=atmega328p -DF_CPU=16000000L -DARDUINO=10805 -DARDUINO_AVR_UNO -DARDUINO_ARCH_AVR   "-I/home/flightlab/arduino-1.8.5/hardware/arduino/avr/cores/arduino" "-I/home/flightlab/arduino-1.8.5/hardware/arduino/avr/variants/standard" "-I/home/flightlab/arduino-1.8.5/hardware/arduino/avr/libraries/EEPROM/src" "-I/home/flightlab/arduino-1.8.5/hardware/arduino/avr/libraries/SPI/src" "/tmp/arduino_build_435484/sketch/triggerbox.ino.cpp" -o "/dev/null"
"/home/flightlab/arduino-1.8.5/hardware/tools/avr/bin/avr-g++" -c -g -Os -w -std=gnu++11 -fpermissive -fno-exceptions -ffunction-sections -fdata-sections -fno-threadsafe-statics  -flto -w -x c++ -E -CC -mmcu=atmega328p -DF_CPU=16000000L -DARDUINO=10805 -DARDUINO_AVR_UNO -DARDUINO_ARCH_AVR   "-I/home/flightlab/arduino-1.8.5/hardware/arduino/avr/cores/arduino" "-I/home/flightlab/arduino-1.8.5/hardware/arduino/avr/variants/standard" "-I/home/flightlab/arduino-1.8.5/hardware/arduino/avr/libraries/EEPROM/src" "-I/home/flightlab/arduino-1.8.5/hardware/arduino/avr/libraries/SPI/src" "/tmp/arduino_build_435484/sketch/triggerbox.ino.cpp" -o "/tmp/arduino_build_435484/preproc/ctags_target_for_gcc_minus_e.cpp"
/home/flightlab/Documents/triggerbox-master/firmware/triggerbox/triggerbox.ino:28:18: fatal error: UDEV.h: No such file or directory
 #include <UDEV.h>
                  ^
compilation terminated.
Using library EEPROM at version 2.0 in folder: /home/flightlab/arduino-1.8.5/hardware/arduino/avr/libraries/EEPROM
Using library SPI at version 1.0 in folder: /home/flightlab/arduino-1.8.5/hardware/arduino/avr/libraries/SPI
exit status 1
Error compiling for board Arduino/Genuino Uno.
```

astraw, 2018-01-27:
Given that you seem to be able to build this from the command line (based on #4), I think the issue must be setting the path in the IDE. The file that cannot be located is at `/usr/share/arduino/libraries/UDEV/UDEV.h`. Here are two ideas.

1) Change `#include <UDEV.h>` to `#include <UDEV/UDEV.h>`
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

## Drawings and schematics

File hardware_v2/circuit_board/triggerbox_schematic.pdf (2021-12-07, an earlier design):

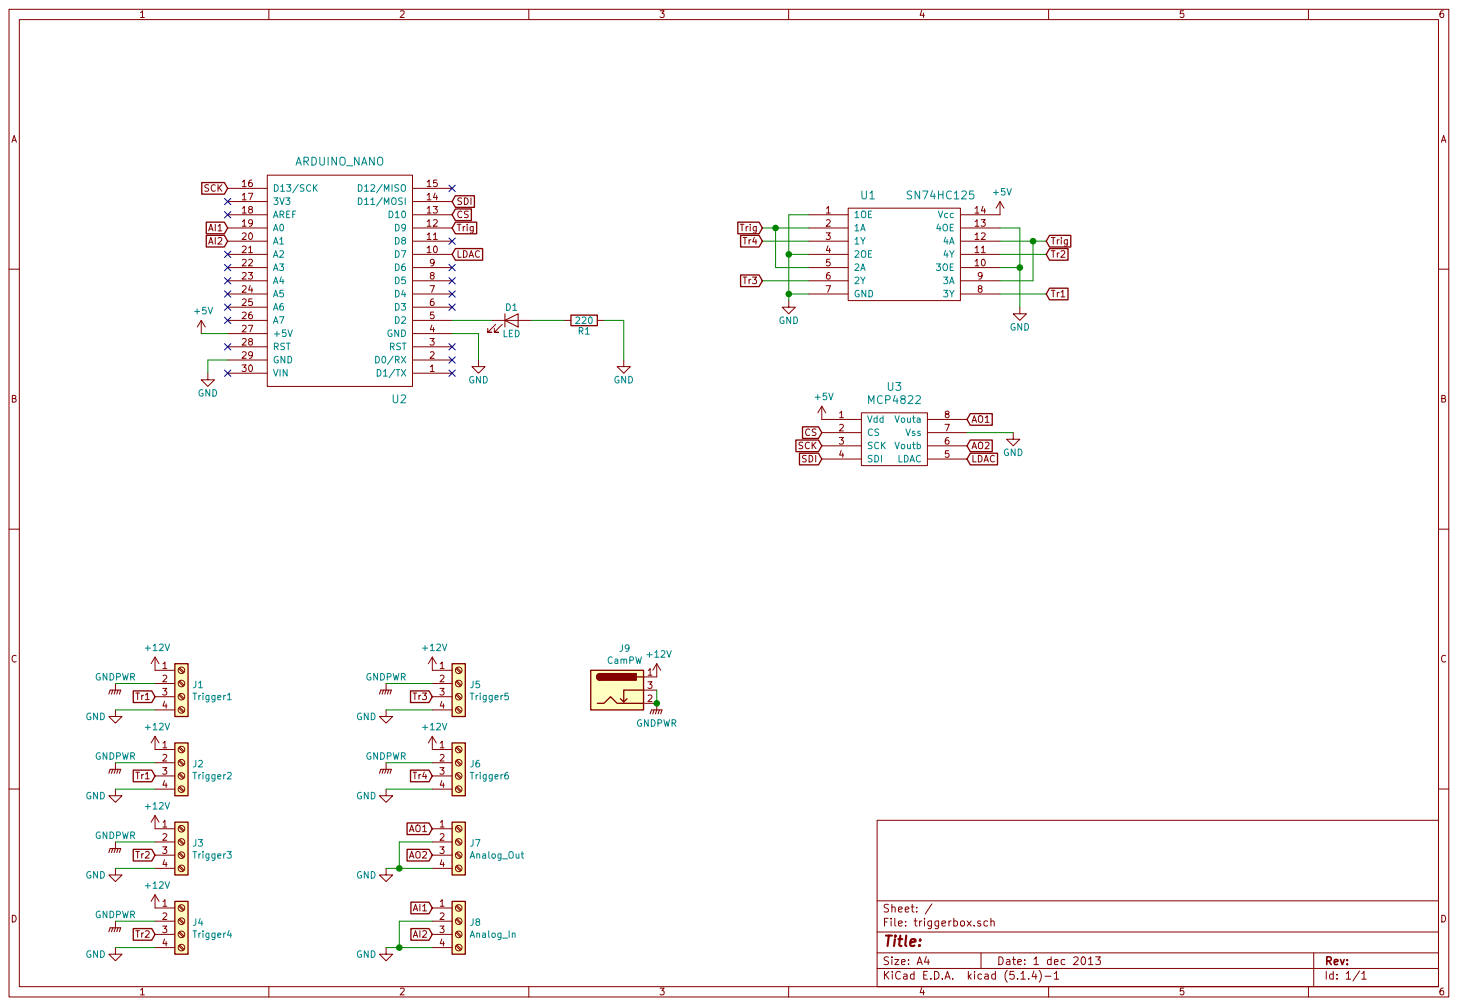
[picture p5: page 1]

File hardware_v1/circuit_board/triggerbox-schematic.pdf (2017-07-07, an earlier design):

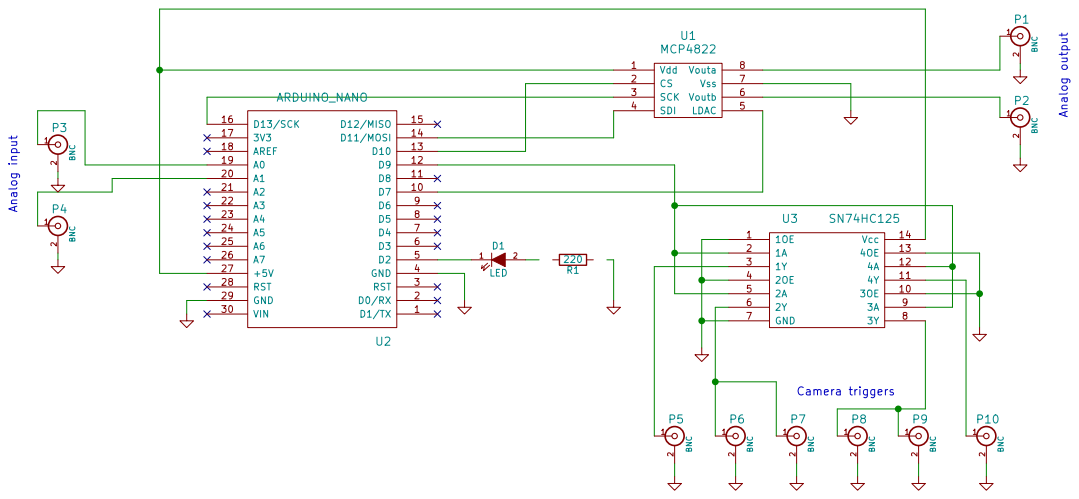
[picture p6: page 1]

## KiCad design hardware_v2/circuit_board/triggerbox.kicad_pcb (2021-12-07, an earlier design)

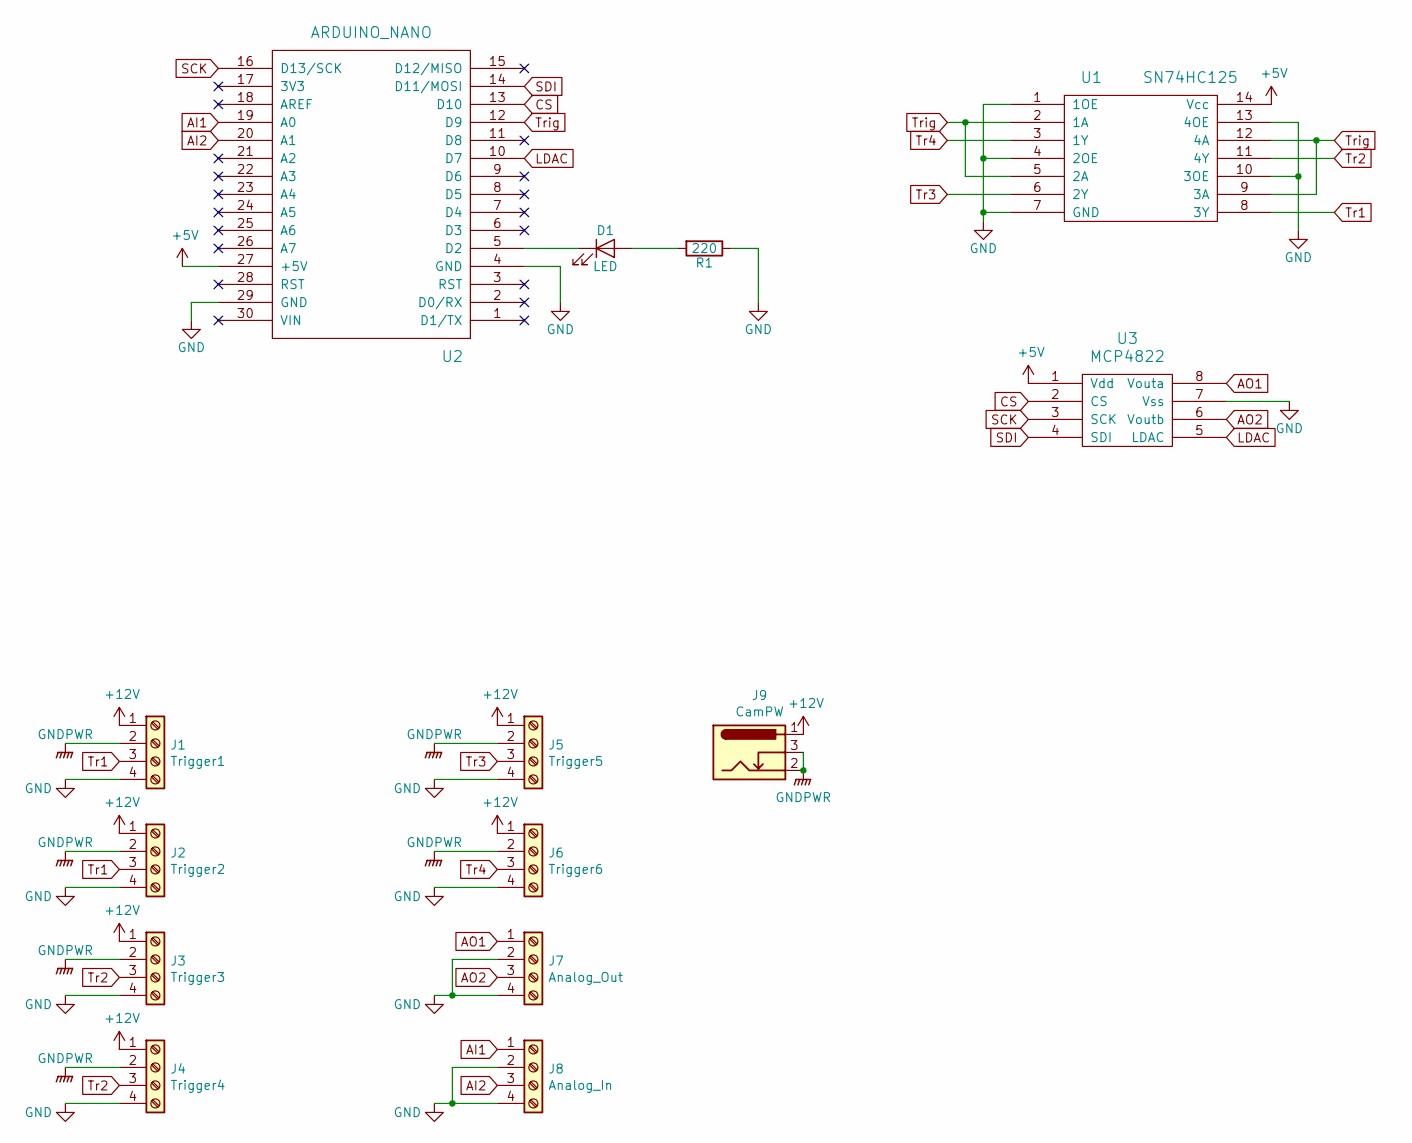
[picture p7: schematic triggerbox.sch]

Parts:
D1: LED; LED_0603_1608Metric
J1: Trigger1; TerminalBlock_bornier-4_P5.08mm
J2: Trigger2; TerminalBlock_bornier-4_P5.08mm
J3: Trigger3; TerminalBlock_bornier-4_P5.08mm
J4: Trigger4; TerminalBlock_bornier-4_P5.08mm
J5: Trigger5; TerminalBlock_bornier-4_P5.08mm
J6: Trigger6; TerminalBlock_bornier-4_P5.08mm
J7: Analog_Out; TerminalBlock_bornier-4_P5.08mm
J8: Analog_In; TerminalBlock_bornier-4_P5.08mm
J9: CamPW; BarrelJack_Horizontal
R1: 220; R_0603_1608Metric_Pad1.05x0.95mm_HandSolder
U1: SN74HC125; SOIC-14_3.9x8.7mm_P1.27mm
U2: ARDUINO_NANO; Arduino_Nano
U3: MCP4822; SOIC-8-1EP_3.9x4.9mm_P1.27mm_EP2.29x3mm

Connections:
+5V: U1.14 (Vcc), U2.27 (+5V), U3.1 (Vdd)
+12V: J1.1, J2.1, J3.1, J4.1, J5.1, J6.1, J9.1
AI1: J8.1, U2.19 (A0)
AI2: J8.3, U2.20 (A1)
AO1: J7.1, U3.8 (Vouta)
AO2: J7.3, U3.6 (Voutb)
CS: U2.13 (D10), U3.2 (CS)
GND: J1.4, J2.4, J3.4, J4.4, J5.4, J6.4, J7.2, J7.4, J8.2, J8.4, R1.1, U1.1 (1OE), U1.4 (2OE), U1.7 (GND), U1.10 (3OE), U1.13 (4OE), U2.4 (GND), U2.29 (GND), U3.7 (Vss)
GNDPWR: J1.2, J2.2, J3.2, J4.2, J5.2, J6.2, J9.2, J9.3
LDAC: U2.10 (D7), U3.5 (LDAC)
unnamed: D1.1 (K), U2.5 (D2)
unnamed: D1.2 (A), R1.2
SCK: U2.16 (D13/SCK), U3.3 (SCK)
SDI: U2.14 (D11/MOSI), U3.4 (SDI)
Tr1: J1.3, J2.3, U1.8 (3Y)
Tr2: J3.3, J4.3, U1.11 (4Y)
Tr3: J5.3, U1.6 (2Y)
Tr4: J6.3, U1.3 (1Y)
Trig: U1.2 (1A), U1.5 (2A), U1.9 (3A), U1.12 (4A), U2.12 (D9)

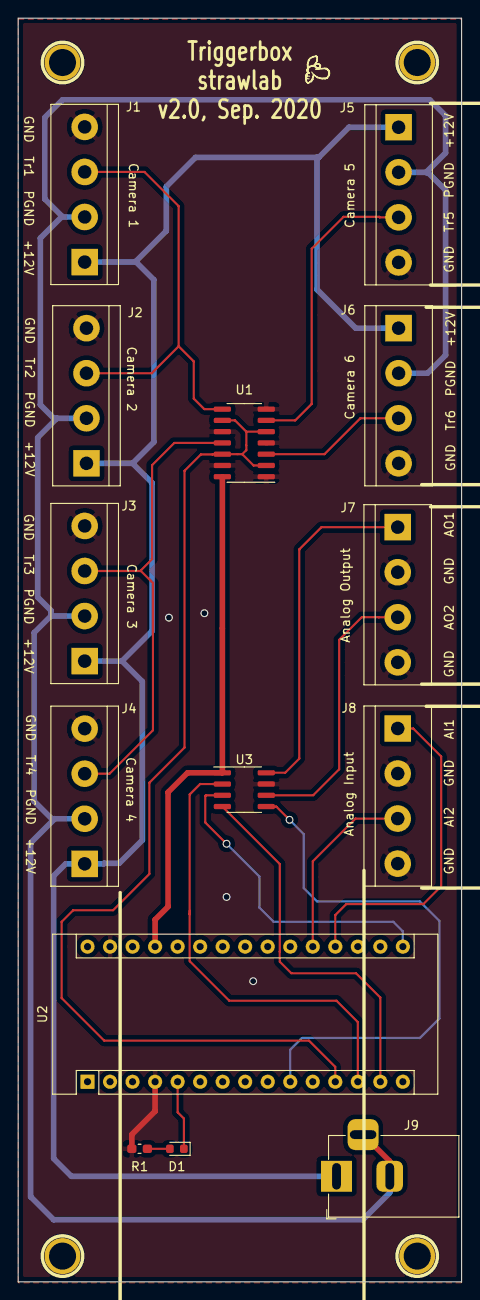
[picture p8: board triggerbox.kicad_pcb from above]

Board: 2 copper layers, 50.0 x 142.5 mm, 18 parts (0 on the bottom side), 19 nets.

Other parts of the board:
1PIN 1: 1; 1pin
1PIN 2: 2; 1pin
1PIN 3: 3; 1pin
1PIN 4: 4; 1pin

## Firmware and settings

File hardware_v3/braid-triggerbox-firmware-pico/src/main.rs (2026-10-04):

// SPDX-License-Identifier: MIT OR Apache-2.0

//! Braid triggerbox firmware for the Raspberry Pi Pico.

#![no_std]
#![no_main]

use defmt_rtt as _;
use panic_probe as _;

#[rtic::app(device = rp_pico::hal::pac, peripherals = true)]
mod app {
    use embedded_hal::digital::OutputPin;

    use heapless::spsc::{Consumer, Producer, Queue};

    use defmt::{debug, info, trace, warn};
    use rp_pico::{
        XOSC_CRYSTAL_FREQ,
        hal::{
            self, Sio, clocks::init_clocks_and_plls, prelude::*, pwm::Slices, timer::Alarm,
            usb::UsbBus, watchdog::Watchdog,
        },
    };

    use embedded_hal::pwm::SetDutyCycle;
    use rtic::{Mutex, mutex_prelude::TupleExt02};

    use usb_device::{class_prelude::*, prelude::*};
    use usbd_serial::SerialPort;

    use braid_triggerbox_comms::{
        DEVICE_FIRMWARE_VERSION, EmulatedNanoPwmClock, PacketParser, Prescaler, SyncVal,
        TopAndPrescaler, UdevMsg, UsbEvent,
    };
    use crc::{CRC_8_MAXIM_DOW, Crc};

    /// Capacity of the queue of events from the host.
    const Q_SZ: usize = 16;

    const CRC_MAXIM: Crc<u8> = Crc::<u8>::new(&CRC_8_MAXIM_DOW);

    const SCAN_TIME_US: u32 = 1_000_000;
    const SCAN_TIME: fugit::Duration<u32, 1, 1_000_000> =
        fugit::Duration::<u32, 1, 1_000_000>::from_ticks(SCAN_TIME_US);

    #[shared]
    struct Shared {
        serial: SerialPort<'static, UsbBus>,
        frame_number: Pulsenumber,
        pwm_slices: Slices,
        timer: hal::Timer,
    }
    #[local]
    struct Local {
        alarm: hal::timer::Alarm0,
        led: hal::gpio::Pin<
            hal::gpio::bank0::Gpio25,
            hal::gpio::FunctionSioOutput,
            hal::gpio::PullNone,
        >,
        usb_dev: UsbDevice<'static, UsbBus>,
        packet_parser: PacketParser,
        event_tx: Producer<'static, UsbEvent>,
        event_rx: Consumer<'static, UsbEvent>,
        pwm_cycle: u8,
        /// A cached copy of what our PWM clock is doing.
        clock_scale: EmulatedNanoPwmClock,
        /// Whether the last requested trigger rate could be produced. If not,
        /// the trigger pulses stay stopped until a rate which can be produced
        /// is requested.
        rate_ok: bool,
    }

    #[expect(
        clippy::expect_used,
        reason = "if the hardware cannot be initialized, there is nothing else to do"
    )]
    #[init(local = [
        usb_bus: Option<UsbBusAllocator<UsbBus>> = None,
        event_queue: Queue<UsbEvent, Q_SZ> = Queue::new(),
    ])]
    fn init(ctx: init::Context<'_>) -> (Shared, Local, init::Monotonics) {
        let mut resets = ctx.device.RESETS;
        let mut watchdog = Watchdog::new(ctx.device.WATCHDOG);
        let clocks = init_clocks_and_plls(
            XOSC_CRYSTAL_FREQ,
            ctx.device.XOSC,
            ctx.device.CLOCKS,
            ctx.device.PLL_SYS,
            ctx.device.PLL_USB,
            &mut resets,
            &mut watchdog,
        )
        .expect("init clocks");

        let mut timer = hal::Timer::new(ctx.device.TIMER, &mut resets, &clocks);

        let usb_bus: &'static UsbBusAllocator<UsbBus> =
            ctx.local.usb_bus.insert(UsbBusAllocator::new(UsbBus::new(
                ctx.device.USBCTRL_REGS,
                ctx.device.USBCTRL_DPRAM,
                clocks.usb_clock,
                true,
                &mut resets,
            )));
        let serial = SerialPort::new(usb_bus);

        let usb_dev = UsbDeviceBuilder::new(usb_bus, UsbVidPid(0x16c0, 0x27dd))
            .strings(&[
                StringDescriptors::default()
                    .manufacturer("Straw Lab")
                    .product("Triggerbox RP2040"), // .serial_number("TEST")
            ])
            .expect("USB string descriptors")
            .device_class(2)
            .build();

        let sio = Sio::new(ctx.device.SIO);
        let pins = rp_pico::Pins::new(
            ctx.device.IO_BANK0,
            ctx.device.PADS_BANK0,
            sio.gpio_bank0,
            &mut resets,
        );
        let mut led = pins.led.reconfigure();
        let Ok(()) = led.set_low();

        let mut alarm = timer.alarm_0().expect("alarm 0");
        if alarm.schedule(SCAN_TIME).is_err() {
            warn!("could not schedule LED timer");
        }
        alarm.enable_interrupt();

        // Init PWMs
        let mut pwm_slices = Slices::new(ctx.device.PWM, &mut resets);

        let clock_scale =
            EmulatedNanoPwmClock::new(50_000, false, clocks.system_clock.freq().to_Hz())
                .expect("initial PWM clock");

        {
            // Configure PWM0
            let pwm0 = &mut pwm_slices.pwm0;
            pwm0.default_config();

            pwm0.set_div_int(clock_scale.div_int()); // To set integer part of clock divider
            pwm0.set_div_frac(0); // No fractional part of clock divider
            let top = clock_scale.to_top();
            pwm0.set_top(top);

            // Output channel A on PWM0 to the GP0 pin
            let channel0 = &mut pwm0.channel_a;
            channel0.output_to(pins.gpio0);

            let Ok(()) = channel0.set_duty_cycle(top / 100);
            pwm0.enable();

            pwm0.enable_interrupt(); // call pwm_irq
        };

        let packet_parser = PacketParser::new();

        let (event_tx, event_rx) = ctx.local.event_queue.split();

        static_assertions::const_assert_eq!(hexchar(0x00), b'0');
        static_assertions::const_assert_eq!(hexchar(0x01), b'1');
        static_assertions::const_assert_eq!(hexchar(0x02), b'2');
        static_assertions::const_assert_eq!(hexchar(0x0A), b'A');
        static_assertions::const_assert_eq!(hexchar(0x0F), b'F');
        static_assertions::const_assert_eq!(hexchar(0x10), b'0');
        static_assertions::const_assert_eq!(hexchar(0x11), b'1');
        static_assertions::const_assert_eq!(hexchar(0x12), b'2');
        static_assertions::const_assert_eq!(hexchar(0x1A), b'A');
        static_assertions::const_assert_eq!(hexchar(0x1F), b'F');

        (
            Shared {
                serial,
                frame_number: 0,
                pwm_slices,
                timer,
            },
            Local {
                alarm,
                led,
                usb_dev,
                clock_scale,
                rate_ok: true,
                packet_parser,
                event_tx,
                event_rx,
                pwm_cycle: 0,
            },
            init::Monotonics(),
        )
    }

    #[idle(
        shared = [serial, frame_number, pwm_slices],
        local = [event_rx, clock_scale, rate_ok]
    )]
    fn idle(mut ctx: idle::Context<'_>) -> ! {
        info!("Started!");
        loop {
            match ctx.local.event_rx.dequeue() {
                Some(ev) => handle_event(&mut ctx, ev),
                None => rtic::export::wfi(), // wait for interrupt
            }
        }
    }

    #[task(
        binds=USBCTRL_IRQ,
        priority = 1,
        shared = [serial, frame_number, pwm_slices, timer],
        local = [usb_dev, event_tx, packet_parser]
    )]
    fn usb_irq(mut ctx: usb_irq::Context<'_>) {
        let mut buf = [0u8; 64];

        let usb_dev = ctx.local.usb_dev;
        let read_result = ctx.shared.serial.lock(|serial| {
            if usb_dev.poll(&mut [serial]) {
                serial.read(&mut buf)
            } else {
                Ok(0)
            }
        });
        if let Ok(count) = read_result
            && count > 0
        {
            let now_usec = ctx.shared.timer.lock(|timer| timer.get_counter());
            let now_usec = braid_triggerbox_comms::Instant::from_ticks(now_usec.ticks());
            let mut data = buf.get(..count).unwrap_or_default();
            // TODO: do not parse packets in IRQ
            // One USB read can hold several commands, so parse until no
            // complete command is left. This terminates because every result
            // except `AwaitingMoreData` consumes buffered data.
            loop {
                match ctx.local.packet_parser.got_buf(now_usec, data) {
                    Ok(ev) => {
                        if let Err(ev) = ctx.local.event_tx.enqueue(ev) {
                            warn!("event queue full, dropping event {}", ev);
                        }
                    }
                    Err(braid_triggerbox_comms::Error::AwaitingMoreData) => break,
                    Err(e) => warn!("error parsing: {}", e),
                }
                data = &[];
            }
        }
    }

    #[task(
        binds = TIMER_IRQ_0,
        priority = 1,
        local = [alarm, led, tog: bool = true],
    )]
    fn timer_irq(ctx: timer_irq::Context<'_>) {
        let Ok(()) = ctx.local.led.set_state((*ctx.local.tog).into());
        *ctx.local.tog = !*ctx.local.tog;

        ctx.local.alarm.clear_interrupt();
        if ctx.local.alarm.schedule(SCAN_TIME).is_err() {
            warn!("could not schedule LED timer");
        }
    }

    #[task(
        binds = PWM_IRQ_WRAP,
        priority = 2,
        shared = [frame_number, pwm_slices],
        local = [pwm_cycle],
    )]
    fn pwm_irq(ctx: pwm_irq::Context<'_>) {
        let p = ctx.shared.pwm_slices;
        let f = ctx.shared.frame_number;

        (p, f).lock(|pwm_slices, frame_number| {
            let pwm0 = &mut pwm_slices.pwm0;
            pwm0.clear_interrupt();
            *frame_number = frame_number.saturating_add(1);
        });
    }

    fn handle_event(ctx: &mut idle::Context<'_>, event: UsbEvent) {
        debug!("handling event: {:?}", event);
        match event {
            UsbEvent::TimestampQuery(value) => {
                let timestamp_request = fill_sample(value, ctx);
                send_data(&timestamp_request, b'P', ctx);
            }
            UsbEvent::VersionRequest => {
                send_data(&fill_sample(DEVICE_FIRMWARE_VERSION, ctx), b'V', ctx);
            }
            UsbEvent::Sync(val) => {
                match val {
                    SyncVal::Sync0 => {
                        // stop clock, reset pulsenumber
                        (&mut ctx.shared.pwm_slices, &mut ctx.shared.frame_number).lock(
                            |pwm_slices, frame_number| {
                                let pwm0 = &mut pwm_slices.pwm0;
                                pwm0.disable();
                                *frame_number = 0;
                                pwm0.set_counter(0);
                            },
                        );
                    }
                    SyncVal::Sync1 => {
                        if !*ctx.local.rate_ok {
                            warn!("Not starting trigger pulses: rate cannot be produced");
                            return;
                        }
                        // start clock
                        ctx.shared.pwm_slices.lock(|pwm_slices| {
                            let pwm0 = &mut pwm_slices.pwm0;
                            pwm0.enable();
                        });
                    }
                    SyncVal::Sync2 => {
                        // stop clock
                        ctx.shared.pwm_slices.lock(|pwm_slices| {
                            let pwm0 = &mut pwm_slices.pwm0;
                            pwm0.disable();
                        });
                    }
                }
            }
            UsbEvent::SetTop(val) => set_top(ctx, &val),
            UsbEvent::SetAOut(val) => {
                // AOUT values
                info!("ignoring AOUT command {}, {}", val.aout0, val.aout1);

                let aout_confirm = fill_sample(val.aout_sequence, ctx);
                send_data(&aout_confirm, b'O', ctx);
            }
            UsbEvent::Udev(val) => {
                match val {
                    UdevMsg::Query => {
                        // Device names are not supported, so report an empty
                        // name.
                        let name = [0u8; 8];
                        let crc = CRC_MAXIM.checksum(&name);
                        let [n0, n1, n2, n3, n4, n5, n6, n7] = name;
                        // Emulate arduino "_serial.print(crc,HEX);" which will
                        // print a single character if the value is less that 0x10.
                        if crc >= 0x10 {
                            let (hi, lo) = (hexchar(crc >> 4), hexchar(crc));
                            send_buf(ctx, &[n0, n1, n2, n3, n4, n5, n6, n7, hi, lo]);
                        } else {
                            send_buf(ctx, &[n0, n1, n2, n3, n4, n5, n6, n7, hexchar(crc)]);
                        }
                    }
                    UdevMsg::Set(_) => {
                        warn!("Ignoring request to set device name: not supported");
                    }
                }
            }
        }
    }

    fn set_top(ctx: &mut idle::Context<'_>, val: &TopAndPrescaler) {
        info!(
            "Received TOP={}, prescaler_key='{}'",
            val.avr_icr1(),
            core::str::from_utf8(&[val.prescaler_key()][..]).unwrap_or("??")
        );

        let is_mode2 = match val.prescaler() {
            Some(Prescaler::Scale8) => false,
            Some(Prescaler::Scale64) => true,
            None => {
                warn!(
                    "Ignoring unsupported prescaler_key: {}",
                    val.prescaler_key()
                );
                return;
            }
        };
        let new_clock_scale = match EmulatedNanoPwmClock::new(
            val.avr_icr1(),
            is_mode2,
            ctx.local.clock_scale.system_clock_freq_hz(),
        ) {
            Ok(new_clock_scale) => new_clock_scale,
            Err(e) => {
                // Rather than trigger at the wrong rate, stop triggering.
                warn!(
                    "Stopping trigger pulses: cannot produce TOP={}: {}",
                    val.avr_icr1(),
                    e
                );
                *ctx.local.rate_ok = false;
                ctx.shared.pwm_slices.lock(|pwm_slices| {
                    pwm_slices.pwm0.disable();
                });
                return;
            }
        };
        *ctx.local.rate_ok = true;
        let top = new_clock_scale.to_top();

        let duty0 = (top / 100).max(1);
        let led_duty = duty0.saturating_mul(2).min(top.saturating_sub(1));
        let div_int = new_clock_scale.div_int();
        *ctx.local.clock_scale = new_clock_scale;

        ctx.shared.pwm_slices.lock(|pwm_slices| {
            let pwm0 = &mut pwm_slices.pwm0;

            // Output channel A on PWM0 to the GP0 pin
            let channel0 = &mut pwm0.channel_a;

            // Output channel B on PWM0 to the GP1 pin
            let channel1 = &mut pwm0.channel_b;

            let Ok(()) = channel0.set_duty_cycle(duty0);
            let Ok(()) = channel1.set_duty_cycle(led_duty);

            pwm0.set_top(top);
            pwm0.set_div_int(div_int);
        });
    }

    type Pulsenumber = u32; /* 2**32 @100Hz = 497 days */

    #[repr(C)]
    struct TimedSample {
        /// value of arbitrary data
        value: u8,
        pulsenumber: Pulsenumber,
        ticks: u16,
    }

    impl TimedSample {
        fn to_bytes(&self) -> [u8; 7] {
            let [p0, p1, p2, p3] = self.pulsenumber.to_le_bytes();
            let [t0, t1] = self.ticks.to_le_bytes();
            [self.value, p0, p1, p2, p3, t0, t1]
        }
    }

    fn send_data(samp: &TimedSample, header: u8, ctx: &mut idle::Context<'_>) {
        let payload = samp.to_bytes();
        let chksum = payload.iter().fold(0u8, |acc, x| acc.wrapping_add(*x));
        let [d0, d1, d2, d3, d4, d5, d6] = payload;
        // The payload length is 7.
        send_buf(ctx, &[header, 7, d0, d1, d2, d3, d4, d5, d6, chksum]);
    }

    fn fill_sample(value: u8, ctx: &mut idle::Context<'_>) -> TimedSample {
        let (pulsenumber, ticks_real) = (&mut ctx.shared.pwm_slices, &mut ctx.shared.frame_number)
            .lock(|pwm_slices, frame_number| {
                let pwm0 = &mut pwm_slices.pwm0;
                (*frame_number, pwm0.get_counter())
            });

        let ticks = ctx.local.clock_scale.scale_ticks(ticks_real);

        TimedSample {
            value,
            pulsenumber,
            ticks,
        }
    }

    fn send_buf(ctx: &mut idle::Context<'_>, out_buf: &[u8]) {
        trace!("out_buf: {:?}", out_buf);
        match ctx.shared.serial.lock(|serial| serial.write(out_buf)) {
            Ok(nbytes) if nbytes == out_buf.len() => {}
            Ok(nbytes) => warn!("only sent {} of {} bytes", nbytes, out_buf.len()),
            Err(e) => warn!("error sending data: {}", defmt::Debug2Format(&e)),
        }
    }

    /// The uppercase hexadecimal digit of the lower 4 bits of `inchar`.
    const fn hexchar(inchar: u8) -> u8 {
        let lower_4_bits = inchar & 0x0F;
        // These cannot overflow because `lower_4_bits` is at most 0x0F.
        if lower_4_bits < 0x0A {
            lower_4_bits.wrapping_add(b'0')
        } else {
            lower_4_bits.wrapping_add(b'A' - 0x0A)
        }
    }
}

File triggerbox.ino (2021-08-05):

/* -*- Mode: C++; tab-width: 4; indent-tabs-mode: nil; c-basic-offset: 4 -*-

triggerbox - trigger box for arduino
====================================

This file contains the source code for the firmware that runs on the
Arduino device. There are two notable things that happen here.


Regular hardware trigger pulse generation
-----------------------------------------

We need to send trigger pulses at a regular interval.

Clock synchronization support
-----------------------------

See the file synchronization.md for information about the theory of
operation. In this firmware, we need to respond to clock requests with
our current clock value. We use the device's timer1 as our official
clock.

 */

#include <Arduino.h>
#include <EEPROM.h>
#include <SPI.h>

// --- start UDEV library ------

/* This UDEV code is included in this file so the whole firmware can be
   distributed as a single Arduino file without having to install libraries. It
   was originally written by John Stowers. It was downloaded from
   https://github.com/strawlab/arduino-udev/tree/f111cc92158d1016ec330455f6811bb8a65aa836/firmware/UDEV.
   It is licensed under the MIT licence.

*/

typedef enum {
    ID_NOP          = 0x00,
    ID_WRITTEN      = 0x01,
    ID_READ         = 0x02,
    ID_FAIL_CRC     = 0x03,
    ID_FAIL_READ    = 0x04
} udev_state_t;

class UDEV {
 public:
  UDEV(HardwareSerial &serial, int pinLed = 13, int eepromBase = 0x0, int maxLen = 8);
  udev_state_t read_and_process(float block = 0, int pin_led = -1, int delay=50);
  udev_state_t process(char cmd, char value);
  void serial_handshake(float block = 5);
  void begin(void);
 private:
  HardwareSerial &_serial;
  int _pinLed;
  int _eepromBase;
  int _maxLen;
};

UDEV::UDEV(HardwareSerial &serial, int pinLed, int eepromBase, int maxLen) :
    _serial(serial),
    _pinLed(pinLed),
    _eepromBase(eepromBase),
    _maxLen(maxLen)
 {
}

udev_state_t UDEV::read_and_process(float block, int pin_led, int del) {

    udev_state_t ok = ID_NOP;

    //convert block to a millisecond counter
    int ms = block*1000;

    int c = -1;

    while (true) {
        if (pin_led >= 0)
            digitalWrite(pin_led, 0x01 ^ digitalRead(pin_led));

        if (!_serial)
            goto pause;

        if (!_serial.available())
            goto pause;

        c = _serial.read();

        if ((c != -1) && ((char)c == 'N'))
            break;

    pause:

        if (ms <= 0)
            break;

        delay(del);
        ms -= del;
    }

    char cmd = c;
    if ((c != -1) && (cmd == 'N')) {
        while (!_serial.available());
        char val = _serial.read();
        ok = process(cmd, val);
    }

    return ok;

}

static byte CRC8(byte *data, byte len) {
    byte crc = 0x00;
    while (len--) {
        byte extract = *data++;
        for (byte i = 8; i; i--) {
          byte sum = (crc ^ extract) & 0x01;
          crc >>= 1;
          if (sum) {
            crc ^= 0x8C;
          }
          extract >>= 1;
        }
    }
    return crc;
}

udev_state_t UDEV::process(char cmd, char value) {

    udev_state_t ok = ID_NOP;

    char name[_maxLen];
    memset(&name,0,_maxLen);

    if (cmd=='N') {
        ok = ID_FAIL_READ;
        if (value=='=') {
            //read the string
            for (int i=0; i<_maxLen; i++) {
                while( !_serial.available() );
                char c = _serial.read();
                name[i] = c;
            }
            //read the crc
            char crc[2] = {0,0};
            while( !_serial.available() );
            crc[0] = _serial.read();
            while( !_serial.available() );
            crc[1] = _serial.read();

            byte crca = strtoul(crc,NULL,16);
            byte crcb = CRC8((byte *)name,_maxLen);

            //if the crc is ok write to the eeprom
            if (crca == crcb) {
                for (int j=0; j<_maxLen; j++) {
                    EEPROM.write( _eepromBase + j, name[j]);
                }
                ok = ID_WRITTEN;
            } else {
                ok = ID_FAIL_CRC;
            }
        } else if (value=='?') {
            for (int j=0; j<_maxLen; j++) {
                char c = EEPROM.read( _eepromBase + j);
                name[j] = c;
                _serial.write(c);
            }

            unsigned char crc = CRC8((byte *)name,_maxLen);
            _serial.print(crc,HEX);

            ok = ID_READ;
        }
    }

    return ok;
}

void UDEV::serial_handshake(float block) {
    udev_state_t ok = read_and_process(block, _pinLed, 20);

    digitalWrite(_pinLed, ok != ID_READ);

    delay(500);
    _serial.flush();
    _serial.end();
}

void UDEV::begin(void) {
    pinMode(_pinLed, OUTPUT);
    _serial.begin(9600);
    delay(50);
}

// ----------------------- end UDEV library

#define WITH_AOUT
#ifdef WITH_AOUT

// ----------------------- start MCP4822 library

/* This MCP4822 code is included in this file so the whole firmware
   can be distributed as a single Arduino file without having to
   install libraries. It was originally written by Will Dickson, IO
   Rodeo Inc. It was downloaded from
   https://bitbucket.org/iorodeo/iorodeo_arduino_libs . It is licensed
   under the Apache 2.0 licence.

*/

#define MCP4822_NUMCHAN 2

enum MCP4822_DAC_CHAN
{
    MCP4822_DAC_A,
    MCP4822_DAC_B
};

class MCP4822
{
private:
    int cs;
    int ldac;
    int gain[MCP4822_NUMCHAN];
    int getCmdWrd(int dac, int value);

public:
    MCP4822();
    MCP4822(int csPin, int ldacPin);
    void setValue(int dac, int value);
    void setValue_A(int value);
    void setValue_B(int value);
    void setValue_AB(int value_A, int value_B);
    void setGain2X(int dac);
    void setGain2X_A();
    void setGain2X_B();
    void setGain2X_AB();
    void setGain1X(int dac);
    void setGain1X_A();
    void setGain1X_B();
    void setGain1X_AB();
    void off_AB();
    void off_A();
    void off_B();
    void off(int dac);
};
// ----------------------------------------------------------------------------
// max4822.cpp
//
// Provides an SPI based interface to the MCP4822 dual voltage output digital
// to analog converter.
//
// Author: Will Dickson, IO Rodeo Inc.
// ----------------------------------------------------------------------------

#define ACTIVE 0b0001000000000000
#define SHUTDOWN 0b0000000000000000
#define GAIN_2X 0b0000000000000000
#define GAIN_1X 0b0010000000000000
#define DAC_A_WRITE 0b0000000000000000
#define DAC_B_WRITE 0b1000000000000000

MCP4822::MCP4822()
{
}

// ----------------------------------------------------------------------------
// MCP4822::MCP4822
//
// Constructor
// ----------------------------------------------------------------------------
MCP4822::MCP4822(int csPin, int ldacPin)
{
    // Configure chip select and latch pins
    cs = csPin;
    ldac = ldacPin;
    pinMode(cs, OUTPUT);
    pinMode(ldac, OUTPUT);
    digitalWrite(cs, HIGH);
    digitalWrite(ldac, HIGH);
    // Set to default configuration
    setGain2X_AB();
}
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

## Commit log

2013-09-06 firmware: cleanup pin assignments
2013-09-07 add direct voltage specification output
2013-09-09 add Fritzing file
    [triggerbox.fzz]
2013-09-11 firmware: makefile defaults to Arduino Nano v3
2013-09-17 don't pause when switching rate
2013-09-17 allow slow framerates (< 30 fps)
2013-12-01 KiCad files
    [triggerbox.sch]
2013-12-01 annotate schematic
    [triggerbox.sch]
2013-12-01 move params PNGs from gerber dir
2013-12-01 as uploaded to silver circuits
2013-12-02 updates (not uploaded yet)
    [triggerbox.brd]
2013-12-19 add first draft of potential triggerbox enclosure
2013-12-20 remove outdated unused Fritzing model
    [triggerbox.fzz]
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2013-12-20 enclosure: closer to production
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2014-01-27 script to set the framerate for a triggerbox_host
2014-01-28 do something more interesting with the external LED
2014-02-12 update for print v3
2014-04-03 comment re: Host inherits from Device
2014-04-04 device: start at 25fps
2014-04-04 api: expose expected_frametate (for set-framerate node)
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2014-05-07 triggerbox_host: stanalone host can set framerate at startup
    client or inprocess users are expected to do similarly
    themselves
2014-05-07 latch expected framerate publisher
2014-06-24 set-name: script to set the device name
2014-11-06 triggerbox_device: use arduino-udev
    this is a generalisation of the set-name and
    named concept of the triggerbox, but with an additional
    udev rule that symlinks the named device into
    /dev/
2014-11-07 remove channel-name support
    this is now supported by arduino-udev creating
    device symlinks
2015-04-08 triggerbox_device: use new arduino-udev api
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2018-01-04 increase error tolerance in individual timestamp samples
    It seems rather rare for a round-trip time to be less than 15 msec,
    which therefore resulted in long delays before enough samples
    accumulated to allow any estimation of the relative clock rates. By
    increasing the allowed error, we make a clock model sooner.
2018-01-28 bugfix: arduino.mk fails when not using default Makefile name
    This fixes #4.
2018-07-23 reset ticks when resetting pulse count
    [triggerbox.ino]
2019-05-10 add rendered versions of the enclosure model
    [enclosure_assembly.scad, enclosure_assembly.stl]
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2021-08-05 include UDEV library in Arduino source
    Also, github CI only tests build, does not package hex file.
2021-08-13 bugfix: ensure all bytes are written
    [lib.rs]
2021-10-13 make max measurement error configurable
    [lib.rs]
2021-10-17 bugfix: compute correct time estimate on arduino
    [lib.rs]
2021-12-07 add triggerbox design with terminal block ouputs
    [base_175.stl, base_200.stl, body.ipt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]
2022-02-09 better version check error
    [lib.rs]
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2022-03-22 compatibility fixes
    Fix for Arduino Nano based hardware. Also refactor and expose new API.
    [lib.rs]
2022-03-22 fix behavior when waiting for version number
    [lib.rs]
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2022-12-16 braid-triggerbox-rs: remove non-backwards compatible firmware
    It was a mistake to include new features only on the Pico-based hardware.
    [lib.rs]
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2022-12-16 braid-triggerbox-firmware-pico: bugfix: many interrupted messages
    [lib.rs]
2022-12-16 braid-triggerbox-rs: slight simplification and tweaks for nano
    The Arduino Nano (https://content.arduino.cc/assets/NanoV3.3_sch.pdf) has
    no connection to the RTS line so we can safely remove the calls that set it.
    The rest of the changes here were tried emperically on an old Nano.
2023-02-03 run 'cargo clippy --fix' with rust 1.67
    [lib.rs]
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2023-11-11 move clock emulation code
    We emulate the Nano PWM clock on the Pico. Move that code to a library
    crate to simplify the specific pico code.
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2026-10-03 chore(deps): update braid-triggerbox dependencies (Claude Opus 5.5)
    Bump thiserror 1 -> 2, nalgebra 0.33 -> 0.35, lstsq 0.6 -> 0.8 and raise
    the minimum versions of the other dependencies to current releases.
    Raise rust-version 1.58 -> 1.89, as required by nalgebra and lstsq.
    Fix a clippy::unnecessary_map_on_constructor lint.
    [lib.rs]
2026-10-03 fix(firmware-pico): drop removed rustc -C inline-threshold flag (Claude Opus 5.5)
    rustc no longer accepts `-C inline-threshold`, which broke the firmware
    build on current stable.
2026-10-03 chore(deps): update firmware-pico dependencies (Claude Opus 5.5)
    Update rp-pico 0.8 -> 0.9 (rp2040-hal 0.10), embedded-hal 0.2 -> 1.0,
    usb-device 0.2 -> 0.3, usbd-serial 0.1 -> 0.2, heapless 0.8 -> 0.9,
    defmt 0.3 -> 1, defmt-rtt 0.4 -> 1 and panic-probe 0.3 -> 1, and port
    the firmware to their new APIs. Remove the unused embedded-time and
    num-traits dependencies.
    Raise rust-version 1.58 -> 1.87, as required by heapless 0.9.
2026-10-03 chore(deps)!: update braid-triggerbox-comms to fugit 0.6 and defmt 1 (Claude Opus 5.5)
    Update fugit 0.3 -> 0.6 and defmt 0.3 -> 1. fugit 0.6 splits Instant
    into wrapping and monotonic kinds; the RP2040 timer is a 64-bit
    microsecond counter, so use MonotonicTimerInstantU64.
    Export the Instant type and have the firmware convert the HAL timer
    value (which is still fugit 0.3) into it.
    The defmt feature now also enables fugit/defmt explicitly rather than
    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
2026-10-03 refactor(braid-triggerbox-comms)!: replace bbqueue with a plain buffer (Claude Opus 5.5)
    PacketParser owned both halves of its bbqueue, so none of bbqueue's
    producer/consumer synchronization was used. It also forced the firmware
    to provide a `static mut` backing store and a thumbv6 feature flag.
    bbqueue 0.6 rewrote the API, and further breaking changes are
    announced before 1.0.
    Accumulate input in an inline [u8; BUF_MAX_SZ] instead. This drops the
    bbqueue dependency, the PacketParser lifetime, the thumbv6 feature and
    the firmware's PARSER_BACKING static, and removes the copy of the
    buffer on each call.
    [lib.rs, main.rs]
2026-10-03 refactor(firmware-pico): make the event queue an RTIC init-local resource (Claude Opus 5.5)
    RTIC init-local resources are &'static mut, so the queue no longer needs
    to be a `static mut`. This removes the last static_mut_refs warning.
    [main.rs]
2026-10-04 ci: update GitHub Actions (Claude Opus 5.5)
    actions/upload-artifact@v3 has been shut down by GitHub, which made the
    Pico firmware job fail. Update it and actions/checkout to v7, and
    arduino/setup-arduino-cli to v2.0.0.
    upload-artifact v4 and later require unique artifact names within a
    workflow run, so suffix the firmware artifact with the runner OS.
    setup-arduino-cli, even in its latest release, targets the deprecated
    Node.js 20, so opt its job into Node.js 24.
2026-10-04 ci: lint and test the whole workspace and the firmware (Claude Opus 5.5)
    `cargo test` and `cargo clippy` in braid-triggerbox-rs only checked the
    root package, so the braid-triggerbox-comms tests never ran in CI. Pass
    --workspace (and --all-targets to clippy), and fix the needless_borrow
    lints this surfaces in the comms tests.
    Also run fmt and clippy on the Pico firmware, which is now warning-free.
    [lib.rs]
2026-10-04 feat(firmware-pico): flash with picotool by default (Claude Opus 5.5)
    The previous default runner, probe-run, requires a debug probe.
    picotool instead loads the firmware over the RP2040 bootloader's
    PICOBOOT USB interface, so a plain USB cable is enough. It is preferred
    over elf2uf2-rs, which hangs writing to the RPI-RP2 drive on recent
    macOS. Update the README accordingly and note Pico W LED behavior.
2026-10-04 build: fix crate metadata for publishing (Claude Opus 5.5)
    Use the SPDX license expression "MIT OR Apache-2.0" instead of the
    deprecated "MIT/Apache-2.0", add repository and homepage to
    braid-triggerbox-comms, and mark the Pico firmware as publish = false.
2026-10-04 docs(firmware-pico): describe installing picotool on Debian and Ubuntu (Claude Opus 5.5)
    Debian 13 and later package picotool. Ubuntu before 26.10 and Debian 12
    do not, so describe building it from source, installing the udev rules
    and the prebuilt binaries from pico-sdk-tools.
2026-10-04 build: strict lints, edition 2024 and release overflow checks (Claude Opus 5.5)
    Forbid unsafe code and enable clippy pedantic plus the restriction
    lints against code which can panic (unwrap_used, expect_used, panic,
    indexing_slicing, arithmetic_side_effects, ...), missing docs and
    `#[allow]` without a reason. clippy.toml relaxes the panic lints in
    tests.
    Move all crates to edition 2024 and the workspace to resolver 3, which
    raises the rust-version of braid-triggerbox-comms to 1.85. Keep integer
    overflow checks in release builds.
    The firmware now needs Rust 1.88 for let chains.
2026-10-04 fix!: never panic in the firmware on data from the host (Claude Opus 5.5)
    The firmware panicked when a single USB read did not fit in the packet
    parser buffer, on an unknown prescaler key, when the event queue was
    full, when a USB write failed and on a request to set the device name.
    It now logs a warning and drops the data instead.
    A TOP value of zero underflowed, and a TOP value too large to represent
    at the Pico PWM clock (below about 7.5 fps with the 64 prescaler)
    silently gave a faster rate than requested. EmulatedNanoPwmClock::new
    now returns PwmClockError::TopOutOfRange, and rather than trigger at the
    wrong rate, the firmware stops the trigger pulses. They stay stopped,
    ignoring S1,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
    [lib.rs, main.rs]
2026-10-04 fix(braid-triggerbox): handle device data without panicking (Claude Opus 5.5)
    The checksum of a packet from the device was computed over the whole
    receive buffer instead of the packet, so a packet followed by any other
    data gave a checksum mismatch error which ended the run loop. Now every
    complete packet in the buffer is handled.
    An unexpected firmware version, payload length or device name CRC
    caused a panic and is now an error. Timestamps were truncated to 32
    bit seconds, which would fail in 2038.
    Document the public API, drop the byteorder dependency and add tests.
    The public API is unchanged.
    [lib.rs]
2026-10-04 chore(deps): track the firmware Cargo.lock (Claude Opus 5.5)
    The firmware is a binary, so commit its lockfile: builds are
    reproducible, and CI (which builds the firmware with --locked) and
    cargo-deny check the versions actually used. The libraries in
    braid-triggerbox-rs keep their lockfile ignored.
2026-10-04 feat(braid-triggerbox)!: take TriggerboxOptions in TriggerboxDevice::new (Claude Opus 5.5)
    TriggerboxDevice::new took seven arguments, so every new option would
    break all callers. It now takes the existing TriggerboxOptions struct,
    and stores query_dt from it, so run_forever no longer takes it as an
    argument.
    This release of braid-triggerbox is breaking anyway, because Cmd
    contains TopAndPrescaler from braid-triggerbox-comms, which also gets a
    breaking release.
    [lib.rs]
2026-10-04 fix(firmware-pico): confirm analog output with an 'O' packet (Claude Opus 5.5)
    The Arduino firmware replies to O= with a packet of type 'O', but the
    Pico firmware sent type 'V'. If the host run loop, rather than the
    SetAOut handler, received this reply, it was taken as a version reply
    with the wrong version, which ended the run loop with an error.
    [main.rs]
2026-10-04 fix(braid-triggerbox-comms): parse N= (set device name) (Claude Opus 5.5)
    N= was not recognized, so the parser dropped it as unknown data and
    then parsed the 8 name bytes and 2 CRC digits which follow it as
    commands. For example, a name starting with 'P' produced a spurious
    timestamp reply. Now N= and the following 10 bytes are parsed as
    UdevMsg::Set. The Pico firmware still cannot store a name and ignores
    it with a warning.
    [lib.rs]
2026-10-04 fix(braid-triggerbox): always send two CRC digits when setting the name (Claude Opus 5.5)
    The device reads exactly two hex digits of CRC after the 8 name bytes,
    but a CRC below 0x10 was sent as a single digit. The Arduino firmware
    then took the first byte of the next command as the second digit, and
    the Pico firmware waited for it.
    [lib.rs]
2026-10-04 fix(firmware-pico): handle every command in a USB read (Claude Opus 5.5)
    Only the first command in each USB read was parsed. Any further commands
    in the same read waited in the parser buffer until the next read, so
    replies lagged behind requests. This happens when the host's writes are
    merged into one USB packet, e.g. T= immediately followed by S1. Now
    parsing repeats until no complete command is left.
    Also raise the event queue capacity from 4 to 16, since one read can
    now produce several events.
    [main.rs]
2026-10-04 fix(braid-triggerbox): resynchronize on corrupted data from the device (Claude Opus 5.5)
    A checksum mismatch or an unexpected payload length ended the run loop
    with an error, so one corrupted byte on the USB link stopped clock
    synchronization until restart. Now the first byte is dropped with a
    warning and parsing continues, so the next valid packet is found.
    Unknown packet types are skipped one byte at a time too, rather than
    trusting their length byte, which could stall parsing for up to 258
    bytes. 'O' (analog output confirmation) packets are recognized and
    ignored.
    Claude-Session: https://claude.ai/code/session_018HDyfb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
    [lib.rs]
2026-10-04 docs: update stale READMEs, comments and demo defaults (Claude Opus 5.5)
    Rewrite the braid-triggerbox README, which described the crate as the
    "flydra triggerbox" and pointed to this repository as the original
    Python implementation. It now describes what the crate does, the
    supported hardware and how to run the demo.
    In the demo, default to /dev/cu.* on macOS (opening /dev/tty.* can block
    waiting for carrier detect) and drop a leftover "Should quit early, but
    cannot" message. In the firmware cargo config, refer to probe-rs, which
    replaced probe-run.
    Claude-Session: https://claude.ai/code/session_018HDyfbQUET2p5pZhdbE8zG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
2026-10-04 ci: make and upload the Pico UF2 once (Claude Opus 5.5)
    The firmware job built and uploaded the same UF2 on Linux, macOS and
    Windows. Keep checking and building the firmware on all three, but make
    and upload the UF2 (now named braid-triggerbox-firmware-pico) only on
    Linux, which also skips installing elf2uf2-rs on the others.
    Claude-Session: https://claude.ai/code/session_018HDyfbQUET2p5pZhdbE8zG
2026-10-04 ci: make the UF2 with the upstream elf2uf2-rs (Claude Opus 5.5)
    Current Rust (LLVM 23) marks the firmware ELF with the GNU OS ABI,
    because the .boot2 and .defmt sections are marked SHF_GNU_RETAIN. The
    strawlab elf2uf2-rs fork rejects that with "Unrecognized ABI". The
    upstream elf2uf2-rs 2.2.0 accepts it, and makes a UF2 identical to that
    of `picotool uf2 convert`. Also pin its version and install it with
    --locked, rather than building the fork's latest commit.
    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
